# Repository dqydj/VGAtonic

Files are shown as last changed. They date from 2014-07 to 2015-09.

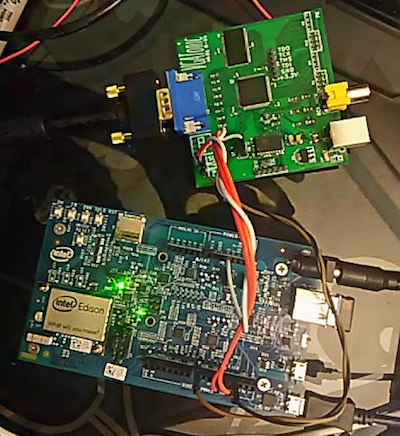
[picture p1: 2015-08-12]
Serial_Framebuffer_Demo/edison.png

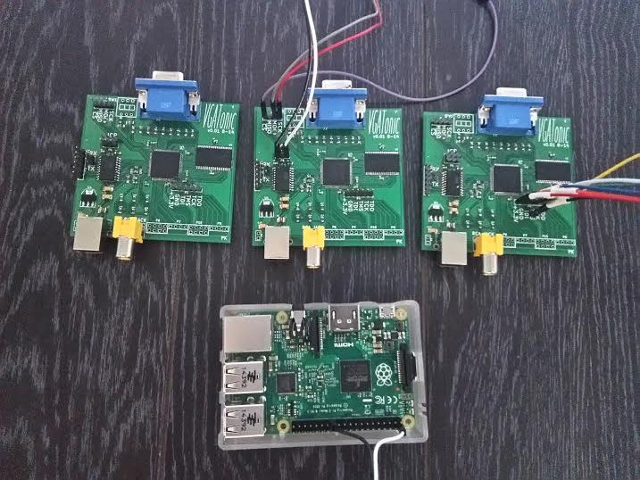
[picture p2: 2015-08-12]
Serial_Framebuffer_Demo/ground.jpg

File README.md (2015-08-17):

VGAtonic
========

4 MBit Video Card supporting up to 640x480 resolution and 8 bit color depth over SPI.  Outputs to any standard VGA Monitor.

**What it is:**

VGAtonic is a video card for adding graphics output to computers, microcontrollers, and devices with SPI output.  It can generally support 5v, 3.3v and 2.5v SPI without level conversion, and can accept SPI of up to 60 MHz (or higher), giving 24.4 FPS as a worst case top speed for it's highest resolution and color depth.  It is also an entry to the [2015](https://hackaday.io/project/6309-vga-graphics-card-vgatonic) and [2014](https://hackaday.io/project/1943-vgatonic) Hackaday Prize competitions.

It additionally has hardware supported accelerations for various things, meaning that slower SPI links can still have useful display output:

 - 640x480 resolution  
 - 320x240 resolution
 - 160x120 resolution
 - 80x60 resolution
 - 8 bit color (256 colors)
 - 4 bit color (16 colors)
 - 2 bit color (4 colors)
 - 1 bit color (black & white)

Last, it also *accelerates screen positioning*, so the entire framebuffer need not be updated for a single refresh (allowing, for example, a menubar at the bottom of the screen to be updated at the full 60 Hz possible in the 640x480 resolution mode).

Importantly, all of these accelerations stack, so if you have a 4 MHz link, you can choose to target, say, 160x120x4 bits for 52 FPS worst case.

**How it's made:**

See the entire parts list in [this Hackaday Prize post](https://hackaday.io/project/6309-spi-and-ttl-serial-vga-graphics-card-vgatonic/log/21984-updated-bill-of-materials).  As part of the project, to keep it *interesting* (and keep costs down) I used modestly spec'd parts - a 144 Macrocell Xilinx XC95144XL CPLD instead of a large FPGA, and an 8 bit 128-Bytes of RAM Atmel ATTiny 2313a Microcontroller instead of one of the larger Atmel parts or something 32-bit (it's not even the largest part in its footprint).  Additionally, the pixel clock is provided by Linear Technology's LTC6903, allowing it to be changed on the fly (and, undoubtedly, tuned for specific monitors) by the microcontroller.  

You can find the schematics in the Rev A directory..

As for the software:

 - KiCad for the layout and Schematic
 - VHDL on Xilinx's ISE Webpack for the CPLD
 - C/C++ for any Microcontroller and Computer glue
 - C for the kernel code for the VGATonic Linux framebuffer drivers
 - Python where necessary

**How it's licensed:**

MIT (Hardware, Firmware, Python Examples, Arduino Code)  

GPL (Linux Framebuffer Drivers, Linux Userspace Code)  

LGPL (Changes to Arduino-Tiny Core)

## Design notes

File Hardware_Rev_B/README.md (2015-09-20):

**NOTE:  This is the current version that should be built.  It has the NTSC pins and almost the same number of GPIOs broken out as Rev A on the optional unpopulated header on the back.**

**For VGA, there is no contest - build Rev B.  You will get more serial speeds, better ground isolation, shielding on the SPI signals, and... LEDs!**

By default, you should try the REGULAR firmware, not the WIDESCREEN firmware.  640x480 at 60Hz is industry standard, so that's the fallback (and it allows 320x240, 160x120 and 80x60 resolutions too for your slower parts or when you want to drive VGATonic over serial).  Once your board is working, the WIDESCREEN firmware is *much* nicer, but it only offers 848x480 and 424x240 resolutions.  It is only tested on rev B, but it likely works on rev A - just be careful.  Note, too, that the TERMINAL EMULATOR only works with the REGULAR firmware, it isn't yet updated for WIDESCREEN.

In this directory you'll find the design documentation for VGAtonic's second design, which we're naming v1.25 or "Rev B".  It is 39% smaller than the first version and contains 54 components (counting the headers and a single component each).

Returning are the Xilinx XC95144 CPLD, the ISSI IS61LV5128AL Memory, and the Linear LTC6903.

We've switched the Atmel 2313a up with the Atmel ATTiny 4313 (it's pin compatible), and clocked it with a 7.3728 MHz crystal which gives us magic frequencies to support lots of new serial speeds.  An external clock also saves us the optional calibration step in programming, which could be a bit of a hassle - now we'll have just two steps for the microcontroller, burning EEPROM then programming the rest.

Oh, we also added LEDs!  That, of course, is the best new feature.

License: MIT (see root directory)

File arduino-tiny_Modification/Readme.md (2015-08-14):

These two files are the minor edits I made to the Hardware Serial code in the arduino-tiny code, which you can find at https://code.google.com/p/arduino-tiny/

VGATonic needs these edits because it handles UART interrupts on its own.

As arduino-tiny is released under an LGPL license, I have included my modified files so you can reproduce my work exactly.

On a Mac, here's the path:

Arduino (Right Click) -> Show package contents

/Contents/Resources/Java/hardware/tiny/avr/cores/tiny/

(Replace the two Hardware Serial files)

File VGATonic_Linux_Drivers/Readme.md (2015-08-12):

**Raspberry Pi:**

Install all of the normal build tools and a recent gcc/g++. You may need an updated kernel - I'm using some 3.18 flavor (no device tree); you can match me like so:

> sudo rpi-update 07179c0ab486d8362af38c6fc99643ded953b99d  
> rpi-source  
> cd into Driver directory  
> sudo make clean  
> sudo make  

Once you've built, here is how you load VGATonic each time (you can automate this, of course!):

> sudo modprobe sysfillrect  
> sudo modprobe syscopyarea  
> sudo modprobe sysimgblt  
> sudo modprobe fb_sys_fops  
> sudo insmod vgatonic.ko  
> sudo insmod rpi_vgatonic_spi.ko  

(You should see activity. Or just do a 'cat /dev/urandom > /dev/fbX' to see writes!)

**Odroid C1:**

I'm on this kernel: Linux odroid 3.10.80-94 for all of these instructions.  Here is how I build on the Odroid:

> sudo -i  
> cd into VGATonic  
> make clean  
> make  

Once it is built, this is how you load it:

> sudo modprobe spicc  
> sudo modprobe spidev  
> sudo modprobe sysfillrect  
> sudo modprobe syscopyarea  
> sudo modprobe sysimgblt  
> sudo modprobe fb_sys_fops  
> sudo insmod vgatonic.ko  
> sudo insmod odroid_vgatonic_spi.ko  

**Beaglebone Black**

For the BeagleBone, you need to load a device tree overlay before anything else to turn on the SPI device.  Since SPI1 interferes with HDMI, I used SPI0.  Here is a tutorial: http://elinux.org/BeagleBone_Black_Enable_SPIDEV .  I do not use a device tree overlay for VGATonic in the driver (yet) for our control pin - so in theory, you should control other things writing to the pin you choose.  Still, this works for me in the 3.8.* kernel:

> cd VGATonic directory  
> make clean; make  

Beaglebone has a lot of stuff loaded for us already, so it's easier to load.

> echo BB-SPI0-01 > /sys/devices/bone_capemgr.*/slots #(assuming you followed the SPI tutorial above and used the default name)  
> sudo insmod vgatonic.ko  

**How Do I Know it Worked?**

There is a test pattern printed when you first load the driver for your platform.  You should see a pachwork of some sort - it is different than the green screen you get when giving VGATonic power for the first time.

The easiest way to know it worked, however, is to get it to react from your platform.  You'll have a new entry in /dev/fb*, so do this:

> cat /dev/urandom > /dev/fbX # X is the new framebuffer number  

You should see random pixels everywhere.  As for how to use your screen, check out the excellent resources Notro has compiled for fbtft.  I have generally tested these platforms by starting the x server then using a browser for a bit just to see how responsive it is.

License:

    VGATonic Linux Framebuffer Driver Code
    Copyright (C) 2015 PK

    This program is free software: you can redistribute it and/or modify
    it under the terms of the GNU General Public License as published by
    the Free Software Foundation, version 2 of the License.

    This program is distributed in the hope that it will be useful,
    but WITHOUT ANY WARRANTY; without even the implied warranty of
    MERCHANTABILITY or FITNESS FOR A PARTICULAR PURPOSE.  See the
    GNU General Public License for more details.

    You should have received a copy of the GNU General Public License
    along with this program.  If not, see <http://www.gnu.org/licenses/>.

> Written with [StackEdit](https://stackedit.io/).

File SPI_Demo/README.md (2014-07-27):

Please see the code for the full details of the implementation, but in summary:

* SPI Slave code with clock domain crossing
* Requires 2 clocks - one SPI clock from the sender, and a 'user mode' clock to run the logic
* Estimated speed is estimated by (3*tUSER + 2*tSU)/7.5 ns, invert for frequency 
        (and please check my math - no warranties implied)
* 2 Flip-Flop synchronization stage for clock domain crossing
* Single byte FIFO for passing SPI byte to user logic

License is MIT

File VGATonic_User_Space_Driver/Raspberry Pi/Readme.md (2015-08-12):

To use:

Edit the code, since we're assuming a 58 MHz SPI device (which isn't common!)

(If you need to build)

gcc raspi_user_spi_test.c -o spitest

(To run: You need a "spidev0.0" device!)

sudo ./spitest

Control-c to exit - but really, insert your code in the loop if you just want to write to the framebuffer!

License:

    VGATonic Linux User Space Code
    Copyright (C) 2015 PK

    This program is free software: you can redistribute it and/or modify
    it under the terms of the GNU General Public License as published by
    the Free Software Foundation, version 2 of the License.

    This program is distributed in the hope that it will be useful,
    but WITHOUT ANY WARRANTY; without even the implied warranty of
    MERCHANTABILITY or FITNESS FOR A PARTICULAR PURPOSE.  See the
    GNU General Public License for more details.

    You should have received a copy of the GNU General Public License
    along with this program.  If not, see <http://www.gnu.org/licenses/>.

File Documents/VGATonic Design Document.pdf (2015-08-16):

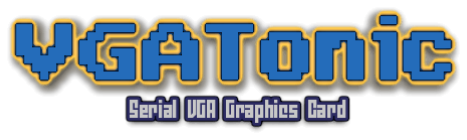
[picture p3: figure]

## VGATonic Serial Graphics Card Hardware System Design Document

## Version 1.0

PK

### 1. Introduction

VGATonic is an open source serial graphics card designed to enable graphical output for microcontrollers, single board computers, and other devices with SPI or Asynchronous TTL Serial output.

VGATonic provides up to 640x480 resolution in 8 bit color using standard VGA timings. The framebuffer memory can be accessed over both SPI and TTL UART.

VGATonic allows hardware accelerated resolutions of 320x240, 160x120, and 80x60. Additionally, it enables accelerated color bit depths of 4, 2, and 1 – and any combination of color depth and resolution. VGATonic also enables hardware accelerated positioning allowing partial frame updates.

In UART mode, VGATonic also exposes a VT52 compatible terminal emulator with 40x15 columns of text along with a built-in font.

### 1.1 Purpose

VGATonic was created as a graphics card with easy to use VGA output when provided input in serial format. It enables easily usable VGA output for low to medium serial speeds by allowing a designer to pick a combination of accelerated bit depths and resolutions acceptable for his or her design.

For applications where only text output is needed or framebuffer modes which fit the available serial speed are too slow, there is a VT52 compatible terminal emulator with a built-in font onboard.

### 1.2 Scope

This version of VGATonic is intended to provide graphical output over VGA in standard 640x480 at 60Hz timings. It requires a driver which can output SPI and/or asynchronous TTL serial, and requires a monitor, television, adapter, capture card, or other device providing VGA input as a consumer of its VGA output.

### 1.3 Overview

This document provides a brief description of some of the specific functions, design decisions, and technical specifications of VGATonic. It is hoped that the reader can create a design utilizing VGATonic's graphical output using this document, The User's Guide and supporting collateral such as schematics, example code, and drivers.

### 2. VGATonic Overview

### 2.1 Product Functions

### 2.1.1. Framebuffer Mode

VGATonic's main mode is a framebuffer mode. Utilizing an onboard 4 Mbit SRAM, VGATonic can accept pixel by pixel data in 8, 4, 2, or 1 bit color depths. VGATonic writes left to right and top to bottom, while the number of writes is determined by the resolution of the screen (and the bit depth). Other than 640x480, VGATonic also does power of two resolution reductions internally, accepting 320x240, 160x120, and 80x60.

VGATonic allows three forms of hardware acceleration in order to improve performance over serial connections. Please see the User's Guide for an in depth description of these modes and a description of the control characters that allow resolution and bit depth changes as well as write positioning.

- Chip Select
- Toggling chip select at any point during a serial transfer (chip select high then low) will reset the framebuffer write pointer to the upper left pixel at location 1 in row 1.
- Hardware Positioning
- Control characters can be used to change the location of the framebuffer write pointer. Positioning changes the row where a serial write will begin.
- Bit Depth and Resolution
- Changing bit depth and resolution from 640x480 in 8 bits primes VGATonic to accept fewer bytes in a given serial transaction.

### 2.1.2. Terminal Emulator Mode

VGATonic includes a terminal emulator onboard with one built in font. It is accessible over asynchronous TTL serial. It provides 40 columns by 15 lines of text and allows a subset (roughly 90%) of VT52 escape codes. Please see the User's Guide for a listing.

### 2.1.3. Administration Mode

Using special escape codes not available on the VT52, VGATonic exposes certain functionality useful for a serial graphics card. Connecting over asynchronous TTL serial, Administration Mode allows toggling UART speed between 9600 baud and 38400 baud. In the case that a device will not sync to VGATonic's VGA output, Administration Mode also allows calibration of the onboard LTC6903 programmable oscillator.

### 2.2 Product Constrains

- 5V Power (most commonly using USB-B input)
- SPI: 5v, 3.3v or 2.5v logic (1 byte transactions)
- (and/or)
- Serial: 3.3v 9600 or 38400 baud 8-N-1 logic

### 2.3 Product Assumptions

VGATonic assumes the availability of a VGA input device, such as a monitor, television, capture card, converter box, or other form of input. It also assumes compatibility with IBM's 1987 VGA standard timings for 640x480 resolution at 60 Hz. It also assumes the availability of a suitable 5 volt power source.

VGA's original 640x480 standard called for 16 colors (4 bit color), and VGATonic goes beyond that specification with 256 color (8 bit) mode available in all resolutions.

Although we assume all existing VGA monitors can handle (or ignore) the added color modes, if you have a classic monitor you will be connecting to VGAtonic please check the monitor's user manual first.

### 3. System Requirements and Specifications

### 3.1 Functionality

VGATonic outputs a constant 640x480 at 60 Hz signal and all processing for lower resolutions and color depths is done internally. VGATonic can multiplex writing and reading with a single buffering schema, and can accept SPI writes faster than the VGA pixel clock.

In UART mode, VGATonic starts up in 9600 baud 8-N-1, but can be toggled to 38400 baud.

### 3.2 Performance

### 3.2.1 Serial Maximum Speeds

- 59.7 MHz Maximum SPI Speed Recommended
- 62.5 MHz tested working on 100% of prototype boards, but technically violates CPLD setup times.
- 9600 or 38400 baud 8-N-1 Asynchronous Serial

### 3.2.2 Serial Voltages

- 5v, 3.3v, or 2.5v SPI
- 3.3v Asynchronous Serial (UART)

### 3.2.3 Resolutions, Bit Depths, and Bits Written

- 640x480 @ 256 Colors
- 2,457,600 bits per frame (307,200 bytes)
- 640x480 @ 16 Colors
- 1,228,800 bits per frame (153,600 bytes)
- 640x480 @ 4 Colors
- 614,400 bits per frame (76,800 bytes)
- 640x480 @ 2 Colors
- 307,200 bits per frame (38,400 bytes)
- 320x240 @ 256 Colors
- 614,400 bits per frame (76,800 bytes)
- 320x240 @ 16 Colors
- 307,200 bits per frame (38,400 bytes)
- 320x240 @ 4 Colors
- 153,600 bits per frame (19,200 bytes)
- 320x240 @ 2 Colors
- 76,800 bits per frame (9,600 bytes)
- 160x120 @ 256 Colors
- 153,600 bits per frame (19,200 bytes)
- 160x120 @ 16 Colors
- 76,800 bits per frame (9,600 bytes)

- 160x120 @ 4 Colors
- 38,400 bits per frame (4,800 bytes)
- 160x120 @ 2 Colors
- 19,200 bits per frame (2,400 bytes)
- 80x60 @ 256 Colors
- 38,400 bits per frame (4,800 bytes)
- 80x60 @ 16 Colors
- 19,200 bits per frame (2,400 bytes)
- 80x60 @ 4 Colors
- 9,600 bits per frame (1,200 bytes)
- 80x60 @ 2 Colors
- 4,800 bits per frame (600 bytes)

### 3.2.4 Theoretical Top Framerate for Full Screen Writes (SPI Only, 59.7 MHz)

- 640x480 @ 8 Bits Per Color: 24.29 Frames Per Second
- 640x480 @ 8 Bits Per Color: 48.58 Frames Per Second
- All other color and resolution combinations: 60 Frames Per Second

### 3.2.5 Power Usage

Typical*: 140 – 170 mA at 5V, 0.7 – 0.85 Watts

If there is a fault condition on the 5V power supply, the 750 mA PTC fuse aboard VGATonic should trip. Once you fix the fault, please wait for the fuse to cool down before providing VGATonic with power again. PTC fuses can take up to 24 hours (even more) to reset.

*VGATonic power usage varies based on mode (UART, SPI). As the VGA standard calls for VGATonic to source current, the average color of the pixels on screen and the rate VGATonic updates internal framebuffer memory also can cause a measurable change in the amount of power used.

### 3.3 Design Constraints

VGATonic was designed with a few requirements in mind:

- Low cost per board
- Ease of use
- Easy to use interfaces
- Very low to medium serial interface speed (No USB 2.0+, PCI, etc.)
- Highly constrained: challenge of CPLD and Tiny Microcontroller vs. FPGA and 32 bit microcontroller.
- Hackability: programmable oscillator and programmable logic and microcontroller
- Power consumption able to run off a USB port

3.4 Applicable Licenses

- MIT:
- All hardware - the PCBs and Kicad collateral.
- CPLD Firmware
- Microcontroller Firmware
- Arduino Framebuffer Driver
- UART Examples
- GPL version 2: (Kernel code and SPIDEV)
- All of the Linux Framebuffer Code
- The Linux User Space Driver code
- Third Party Licenses:
- LGPL:
- arduino-tiny core
- https://code.google.com/p/arduino-tiny/

### 3.5 Applicable Standards

- 8-N-1 3.3V TTL Serial at 9600 or 38400 baud
- SPI at 5v, 3.3v, or 2.5v
- (Commonly Mode 0 or 3, but there is no official SPI standard)
- 640x480 @ 60Hz Industry Standard (IBM) VGA timing
- VT52 Compatible Terminal Emulator Escape Codes

### 4. Parts Selection

(Footprints/PCB Part Labels are in Github)

1 × Xilinx XC95144XL 144 Macrocell CPLD
1 × Atmel Corporation ATTiny 2313a Microcontroller
1 × ISSI IS61LV5128AL-10 100 MHz 4MBit Static Ram
1 × Linear Technology LTC6903 Programmable Oscillator
1 × ON Semiconductor NCP1117ST33T3G 3.3V Low Dropout Voltage Regulator 12 × 0.1 uF Capacitor 0603 Capacitor
2 × 10 uF Capacitor 1206 Capacitor
1 × 47 uF Capacitor 1206 Capacitor
1 × 1 uF Capacitor
1 × Bourns MF USMF075-2 .75 Amp PTC Fuse
1 × USB-B Jack Power Supply, Multicomp USB-B-S-RA 1 × VGA Port TE Connectivity 1734344-1
6 × 10k Ohm Resistor 0805
1 × 4.7k Ohm Resistor 0805
4 × 510 Ohm Resistor 0805
5 × 1k Ohm Resistor 0805
4 × 2k Ohm Resistor 0805
1 × 4k Ohm Resistor 0805
1 × 1.5k Ohm Resistor 0805
1 × RCA Jack (Optional) Switchcraft PJRAN1X1U04X (For future optional firmware swap)

(Please see the User's Guide for a detailed build guide.)

### 5. System Block Diagram

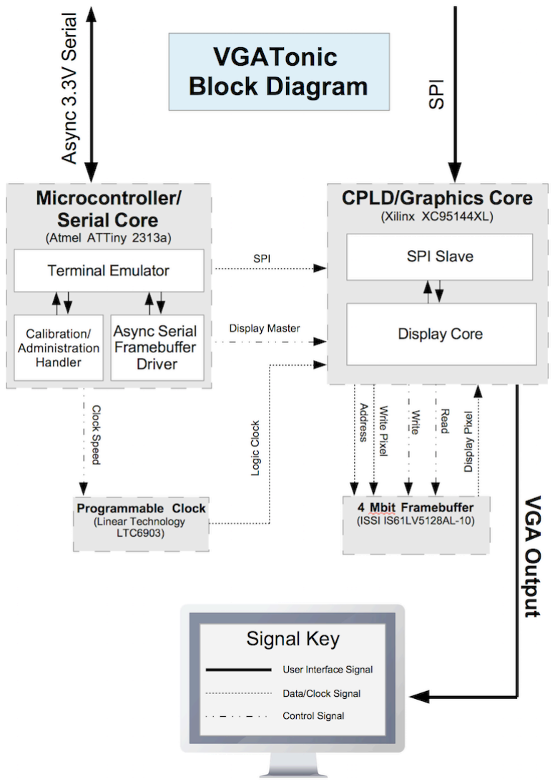
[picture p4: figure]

### 6. Future Work

There are two main places VGATonic could build towards:

VGATonic has sufficient GPIOs to develop RCA/component output, albeit not at the same time as VGA output. Eventually, it would be nice to have an alternative firmware for NTSC output. PAL output should also be doable.

VGTonic has sufficient framebuffer memory to target 800x600 at 8 bit color resolution. This mode isn't supported to the degree that 640x480 at 60 Hz is, but would be a valuable additional firmware for users to install for specific cases where more resolution was needed.

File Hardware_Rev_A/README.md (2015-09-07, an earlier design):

**NOTE: For most purposes, you should build REVISION B.  Please exit this directory and go to Rev B.  It is smaller, it doesn't require extra code to work around an error in the schematic, it supports more serial speeds, and it has better ground planes and shielding for SPI signals.  It also has LEDs!**

**The only reason you should build this version is for easy access to RCA and the GPIOs.  Revision B has all the same pins broken out on a .4mm pitch header, which is harder to access, but is superior in all other ways!8**

In this directory you'll find the design documentation for VGAtonic's first reference design, which we're naming v0.01 or "Rev A"

We've added three systems to the board to make it easier to develop the firmware.  An LTC6903 (http://www.linear.com/product/LTC6903 , up to 68 MHz) will handle the clocking duty for VGAtonic.  It is controlled by an ATTiny2313.  (I've routed a few additional lines between the CPLD and the ATTiny for user expansion.)

We've also added a Gadget Factory Papilio (http://papilio.cc/) compatible (other than the 2.5v pin) header at the bottom, with two slots.  16 CPLD GPIOs are routed there.  Another 3 are routed to the switch near the VGA connector.

All in all, about 3"x3", and $30 for 10 shipped from http://www.elecrow.com/ (DHL option when I purchased mine)

License: MIT (see root directory)

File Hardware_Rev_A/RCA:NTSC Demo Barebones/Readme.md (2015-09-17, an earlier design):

**This Firmware should ONLY be used with the Rev A version of the board, unless you populate the header on the back of rev B and build a DAC for the NTSC signals.  (That is left as an exercise for the rev B reader)**

*Also, this is a proof of concept - **you should use the VGA output**.  There are nonstandard frequencies everywhere, and it's luck of the draw how close the LTC6903 on your board will get to NTSC's colorburst frequency.  VGA is much more tolerant of small errors, while even being 15000 off NTSC's 3.57 MHz (that's just a .4% error!) burst will create a rainbow from a single color.*

To use this with a rev A Board:

 1. In the Microcontroller firmware, edit the LTC6903 programming lines until you have an acceptable color burst frequency.  Datasheet is here http://www.linear.com/product/LTC6903
 2. 	 bitbang_byte_out(0b11100001); bitbang_byte_out(0B10100110);
	 3. (In theory, DAC should be 100, but I needed to use 105.  I also got .07% error instead of .00%)
 3. Program the microcontroller
 4. Program the CPLD

The released firmwares should work if you set the speeds below 21.9 MHz SPI, and note that color depth is 4 bits while resolution is 320x240.  This might require recompilation.

As for the TTL Serial support?  It works, but only in framebuffer mode.  Send only 320x240@4bpp or you'll get weirdness on the screen.

After that?  Use it just like you would a regular VGA VGATonic - I've tested it on all three NTSC accepting screens here, and while the colors are all slightly different ('Never The Same Color' is a joke for a reason), they all attempt to produce a picture even with my non-standard colorburst frequency.

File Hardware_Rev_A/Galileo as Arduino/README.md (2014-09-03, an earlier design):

This code runs on an Intel Galileo modified as mentioned in this post:

http://hackaday.io/project/1943/log/8757-the-project-deadline-limbo

Once you increase the allowed sketch size your Galileo should have no problem running this code.

Pins needed:
13: SCK
11: MOSI
10: CS

Optional:
5v
GND

Steps:
1) Get the python script in this directory, edit the line which refers to picture name
2) Find a way to install the PIL, Python Imaging Library, http://www.pythonware.com/products/pil/
3) Format your picture as 640x480.  Optional: use Photoshop or similar to limit the color palette.
4) Copy guitars.h / doge3.h with the output of the script.
5) Upload, be wowed!

We'll do Linux next.

License: See main directory, still MIT.

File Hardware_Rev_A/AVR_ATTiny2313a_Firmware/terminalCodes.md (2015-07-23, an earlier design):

## VGATonic vt52 Compatible Escape Codes ##

Here is a list of vt52 compatible escape codes supported by VGATonic.  Due to the very small RAM (128 Bytes), there isn't enough room to implement any of the multi-line commands.  However, this covers the major commands for most applications.

Hit escape, then hit the following character to execute the commands:

    A - Move the cursor to beginning of line above.
    B - Move the cursor to beginning of line below.
    C - Move the cursor right by one.
    D - Move the cursor left by one.
    E - Clear the screen and place the cursor in the upper left corner.
    H - Move the cursor to the upper left corner.
    I - Move the cursor to beginning of line above.
    J - Erase all lines after our current line
    K - Clear the current line from the current cursor position.
    M - Delete the current line.
    Y - 'Goto' Coordinate mode - first will change line number, then cursor position (both ASCII - 32)
    b - Byte after 'b' sets new foreground color.
    c - Byte after 'c' sets new background color.
    d - Erase all lines above current line.
    e - Enable the cursor.
    f - Disable the cursor.
    l - Erase current line line and place the cursor at the beginning of the row.
    o - Erase the current line from the beginning to the current cursor.
    p - Invert background and foreground color.
    q - Invert background and foreground color.

Special VGATonic Only Escape Codes
----------------------------------

Hit escape, then hit the following character to execute the commands:

    % - Administrator Mode
    W - 'W'rite framebuffer mode (pass through pixels from UART, 255 at a time)
    Z - Send control character to VGATonic.  (Position or Resolution or Bit Depth change)
    m - Become 'm'aster of CPLD (Disable external SPI writes and put Microcontroller in control)
    r - 'r'elease CPLD (Allow external SPI writes)
    s - 's'elect CPLD (Warn CPLD a new frame write is coming)
    u - 'u'nselect CPLD (Inform CPLD current frame write is done)
  
  **Special VGATonic Only Administrator Escape Codes ( Esc-%-(code) )**
  
    < - 9600  Baud Serial Terminal (Default)
    > - 38400 Baud Serial Terminal
    + - Add one to LTC6903 PLL Scaler
    - - Subtract one from LTC6903 PLL Scaler
    & - VGATonic default PLL Scaler, 0B01011110
    | - Burn current PLL Scaler to EEPROM
  
  **When done with VGATonic escape modes, to get back to the serial terminal, here's what I do:**
  
    Escape - m     (master)
    Escape - s     (select CPLD)
    Escape - Z r ( 160x120 @ 8bpp screen)
    Escape - E     (Clear the screen)

**When calibrating a new VGATonic:**

    Escape - % - to decrease the pixel clock (That's a single minus)
    Escape - % + to increase the pixel clock
    Escape - % | to burn scaler to EEPROM (will retain between 
    powerups)
    
**If your monitor won't sync to the VGATonic clock:**

  Escape - % & to reset the LTC Calibration bit to factory
  Escape - % | to burn the factory bit to EEPROM

> Written with [StackEdit](https://stackedit.io/).

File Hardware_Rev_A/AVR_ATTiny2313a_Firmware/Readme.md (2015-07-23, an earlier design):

## Burning Firmware ##

This is a two step process.

The very first time you run, you should uncomment the line in AVR_ATTiny2313a_Firmware.ino which says:

    //#define EEPROM_UPDATE 1 // Uncomment when you want to write EEPROM, otherwise leave this alone.

The function updateEEPROM() in utilities.ino controls what happens during the EEPROM write.  You should change the:

    eeprom_update_byte (( uint8_t *) OSCALSPEED, 'K' );

line (or at least the 'K') to something.  I am making one board at a time, so I just send ‘u’ over serial at 9600 baud until I have a value which is 1/9600 seconds long.  See Jason Pepas’s example 
here: https://github.com/pepaslabs/CalibrateATtiny85OSCCAL 

The *second* run, comment that line out - you’re ready to program again.  Connect at 9600 baud and do this:

    Escape - m (Master mode)
    Escape - s (Select CPLD)
    Escape - Z - r (Set to 8 bit color depth at 160x120 resolution, since we don't know what we were in.)

Now send it a bunch of random characters - congratulations, you are talking to a serial terminal emulator… in only 128 Bytes of RAM!!!

It is based on vt52 escape codes, but… 128 bytes of RAM, so we can’t do multi-line functions, wraps, and inserts.  We handle most of the codes, however.  See terminalCodes.md for all of the codes.

> Written with [StackEdit](https://stackedit.io/).

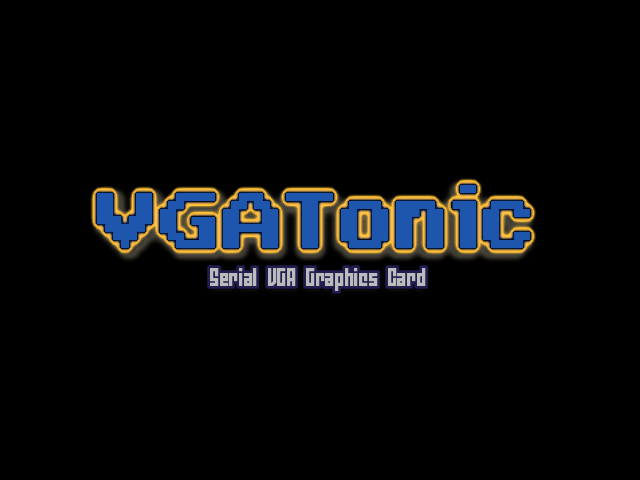
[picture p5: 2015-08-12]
Serial_Framebuffer_Demo/VGATonic.png

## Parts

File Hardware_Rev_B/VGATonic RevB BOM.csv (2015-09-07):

Reference | Value | Footprint | Cost / Board | Supplier | Quantity Required | Notes
IC1 | ATTINY4313 | Housings_SOIC:SOIC-20_7.5x12.8mm_Pitch1.27mm | 1.59 | Newark | 1
C1 | 0.1uF | Capacitors_SMD:C_0603 | 0.00359 | Digikey | 4000 | X7R
C2 | 0.1uF | Capacitors_SMD:C_0603 | 0.00359 | Digikey | 4000 | X7R
C3 | 0.1uF | Capacitors_SMD:C_0603 | 0.00359 | Digikey | 4000 | X7R
C4 | 0.1uF | Capacitors_SMD:C_0603 | 0.00359 | Digikey | 4000 | X7R
C5 | 0.1uF | Capacitors_SMD:C_0603 | 0.00359 | Digikey | 4000 | X7R
C6 | 0.1uF | Capacitors_SMD:C_0603 | 0.00359 | Digikey | 4000 | X7R
C7 | 0.1uF | Capacitors_SMD:C_0603 | 0.00359 | Digikey | 4000 | X7R
C8 | 0.1uF | Capacitors_SMD:C_0603 | 0.00359 | Digikey | 4000 | X7R
C9 | 0.1uF | Capacitors_SMD:C_0603 | 0.00359 | Digikey | 4000 | X7R
C10 | 0.1uF | Capacitors_SMD:C_0603 | 0.00359 | Digikey | 4000 | X7R
C11 | 0.1uF | Capacitors_SMD:C_0603 | 0.00359 | Digikey | 4000 | X7R
C12 | 1uF | Capacitors_SMD:C_0603 | 0.1 | Digikey | 1 | X7R
U3 | IS61LV5128AL | Footprints:tsop2-44 | 4.85 | Jameco | 1
U1 | LTC6903 | Housings_SSOP:MSOP-8_3x3mm_Pitch0.65mm | 3.92 | Digikey | 1
U2 | XC95144PQ100-100TQFP | Housings_QFP:TQFP-100_14x14mm_Pitch0.5mm | 7.25 | Digikey | 1
R2 | 4.7k | Resistors_SMD:R_0805 | 0.018 | Digikey | 10 | 5.00%
R1 | 10k | Resistors_SMD:R_0805 | 0.018 | Digikey | 10 | 5.00%
R3 | 10k | Resistors_SMD:R_0805 | 0.018 | Digikey | 10 | 5.00%
R4 | 10k | Resistors_SMD:R_0805 | 0.018 | Digikey | 10 | 5.00%
FID1 | CONN_01X01 | Fiducials:Fiducial_1mm_Dia_2.54mm_Outer_CopperTop | 0 |  |  | 5.00%
FID2 | CONN_01X01 | Fiducials:Fiducial_1mm_Dia_2.54mm_Outer_CopperTop | 0 |  |  | 5.00%
R11 | 510 | Resistors_SMD:R_0805 | 0.021 | Digikey | 10 | 1.00%
R12 | 1k | Resistors_SMD:R_0805 | 0.021 | Digikey | 10 | 1.00%
R13 | 2k | Resistors_SMD:R_0805 | 0.021 | Digikey | 10 | 1.00%
R8 | 510 | Resistors_SMD:R_0805 | 0.021 | Digikey | 10 | 1.00%
R9 | 1k | Resistors_SMD:R_0805 | 0.021 | Digikey | 10 | 1.00%
R10 | 2k | Resistors_SMD:R_0805 | 0.021 | Digikey | 10 | 1.00%
R5 | 510 | Resistors_SMD:R_0805 | 0.021 | Digikey | 10 | 1.00%
R6 | 1k | Resistors_SMD:R_0805 | 0.021 | Digikey | 10 | 1.00%
R7 | 2k | Resistors_SMD:R_0805 | 0.021 | Digikey | 10 | 1.00%
F1 | 0.75A HOLD 6V PTC | Resistors_SMD:R_1210 | 0.2544 | Newark | 10
U4 | NCP1117ST33T3G | Footprints:SOT223_PWR | 0.49 | Digikey | 1 | LDO Not Needed
C14 | 10uF | SMD_Packages:SMD-1206_Pol | 0.4848 | Newark | 5 | Tantalum, 6.3V
C15 | 10uF | SMD_Packages:SMD-1206_Pol | 0.4848 | Newark | 5 | Tantalum, 6.3V
C13 | 47uF | SMD_Packages:SMD-1206_Pol | 0.0672 | Newark | 1 | Tantalum, 6.3V
P6 | CONN_02X03 | Pin_Headers:Pin_Header_Straight_2x03 | 0.06
J2 | VGA-HD-15 | Footprints:HD15_B-HD15F | 1.18 | Newark | 1 | Newark 54M6031
C16 | 22pF | Capacitors_SMD:C_0603 | 0.024 | Digikey | 10 | X7R
C17 | 22pF | Capacitors_SMD:C_0603 | 0.024 | Digikey | 10 | X7R
Y1 | 7.3728 MHz | crystal:HC49_sm | 0.325 | eBay | 20 | MFG Not Important
P1 | CONN_01X03 | Pin_Headers:Pin_Header_Straight_1x03 | 0.03
P2 | CONN_01X05 | Pin_Headers:Pin_Header_Straight_1x05 | 0.05
P3 | CONN_01X02 | Pin_Headers:Pin_Header_Straight_1x02 | 0.02
P4 | CONN_02X03 | Pin_Headers:Pin_Header_Straight_2x03 | 0.06
P7 | CONN_01X30 | Footprints:DF40C-30DS-0.4V |  |  |  | Optional
D1 | Green LED | LEDs:LED-0603 | 0.0495 | Jameco |  | You Pick Color
R14 | 330 Ohm | Resistors_SMD:R_0805 | 0.212 | Digikey |  | 5.00%
R15 | 150 Ohm | Resistors_SMD:R_0805 | 0.212 | Digikey |  | 5.00%
R16 | 150 Ohm | Resistors_SMD:R_0805 | 0.194 | Digikey |  | 5.00%
D2 | Yellow LED | LEDs:LED-0603 | 0.0495 | Jameco |  | You Pick Color
D3 | Orange LED | LEDs:LED-0603 | 0.0495 | Jameco |  | You Pick Color
P5 | USB_B | Connect:USB_B | 0.5528 | Newark |  | Newark 14N8154
 |  |  | 22.88399

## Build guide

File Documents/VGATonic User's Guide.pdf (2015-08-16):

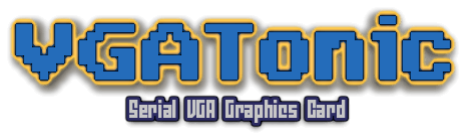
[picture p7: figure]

# User Guide and Reference Manual

# Getting Started

Providing Power
VGATonic needs to be provided with 5V in order to work.

Connect VGATonic's USB Type B port to an open USB port on the device which will be using the VGATonic video card. (If there are no USB ports available or you would prefer to power VGATonic in another way, please see the power labels on the PCB picture in the Appendix.)

Note that if you don't power VGATonic from the board you will be using to drive it, you should also connect a jumper between ground on the driver and ground on VGATonic to have a good reference. See the Appendix for grounding points onboard VGATonic.
Connecting VGA
Once power is provided to the board, connect a VGA cable between VGATonic's VGA port and a VGA port on your monitor, TV, converter, or other device.
Be careful you do not connect VGATonic to a device which provides VGA output – you can destroy VGATonic or the other device! Double check you are only connecting VGATonic to an output device or a converter which accepts VGA input.
If all is connected and your device didn't already autodetect VGATonic, switch your device on and set the device's input to VGA. You may need to read the user manual for instructions on how to do that for your unique situation.
VGATonic starts up with an all green screen; if your device is connected to VGATonic and displays a green screen – congratulations, VGATonic is powered up and working! You are now ready to pick a mode and start using VGATonic as a framebuffer or terminal emulator!

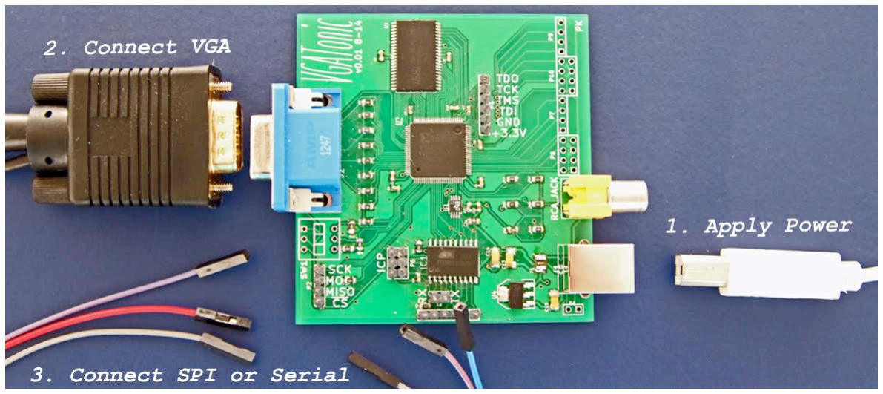
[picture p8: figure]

## VGATonic Usage Modes – Connecting SPI and Serial

VGATonic has two main forms of communication which are available – 5v/3.3v/2.5v SPI or 3.3v Asynchronous Serial (also known as “TTL RS-232” or “TTL Serial”). Using those protocols, three display modes and one administration mode are available:
SPI:
- Framebuffer
TTL Serial:
- Framebuffer
- VT52 Compatible (Subset) Terminal Emulator
- Administration Mode

You may use Serial and SPI at the same time, although only one can be the master at once.

## SPI Modes

SPI Framebuffer
The only available SPI mode is the SPI framebuffer. The easiest way to get started with SPI is to use the drivers we provide on Github and one of our supported boards, although we have provided enough examples for you to port to the platform of your choice. As of this printing, we have provided driver examples for the Raspberry Pi 2 Model B, The Odroid C1, the BeagleBone Black, and the Intel Edison with Arduino Breakout Board. We have also provided user mode drivers and Arduino driver code. The SPI header onboard VGATonic contains “SCK”, “MOSI”, “MISO” and “CS” (Chip Select) pins -but “MISO” can go unconnected. The pins in the table are board dependent and go by the board's naming conventions. You can, of course, change these in the drivers, but these are what we used and must be used if you do not change code:

For a description of the SPI protocol in order to write your own driver, please see the Hacker's Guide, or take a look at some of the code in our repository.

| Chip Select | MOSI | SCK | CS Label | MOSI Label | SCK Label
Raspberry Pi 2 Model B | 22 | 19 | 23 | BCM 25 | BCM 10 (MOSI) | BCM 11 (SCLK)
Odroid C1 | 22 | 19 | 23 | #103 | #107 | #105
BeagleBone Black | 15 | 18 | 22 | GPIO_48 | SPIO_D1 | SPIO_SCLK
Intel Edison | 8 | 11 | 13 | 49 | 43/SPI_2_TXD | 40/SPI_2_CLK
Arduino Uno | 9 | 11 | 13 | 9 | 11 | 13

## Asynchronous Serial Modes

VT52 Compatible Terminal Emulator

VGATonic includes a VT52-like terminal emulator, which provides a subset of VT52 escape codes as well as VGATonic specific (and unique – do not try on a working VT52) escape codes and administrator escape codes. It also includes a single font in memory.
When VGATonic starts up, it quickly initializes the oscillator and prints a green screen, and puts the SPI bus in charge of the VGA Output. In order to use the terminal emulator, you must connect over serial and put the terminal emulator in charge. Connect over TTL Serial at 9600 baud 8-N-1 (please see your serial device's manual for information on how to connect; it is beyond the scope of this document. On a Macbook, I use a USB to Serial Adapter and the 'screen' program in a terminal to connect.) The TX and RX pins onboard VGATonic should be used to connect to serial – ensure you properly connect your serial device.

Escape m # (Master mode)
Escape s # (Select CPLD)
Escape Z r # (Set to 8 bit color depth at 160x120 resolution, since we don't know what we were in.)

To ensure the serial connection now has control of the display driver, you can now send ASCII characters to VGATonic and see if they are printed on your screen. 'Escape E' (capital 'E') clears the screen and moves the cursor to the upper left.
If it works – congratulations! The terminal emulator is simply the easiest way to add VGA output to a project, as the serial protocol is widely supported at 9600 baud. Any microcontroller or TTL serial output that supports 8-N-1 serial at 3.3 volts can communicate with VGATonic and display characters and colors on the screen. It is particularly useful as a debugging output window for projects with serial available.
A complete copy of all codes supported can be found in the Appendix. Information on how to use high-speed 38400 baud mode is in the Administration section below.
To give control of the display driver back to the SPI connection, either power cycle VGATonic or use this command sequence over serial:

Escape Z r 0 (Set to 8 bit color depth at 640x480 resolution, since we don't know what we were in.) Escape u # (Unselect CPLD)
Escape r # (Release master mode)

Asynchronous Serial Framebuffer

While using the terminal emulator, VGATonic has special escape codes which allow you to directly write pixels to the screen. While 640x480x8bpp will be painfully slow even at 38400 baud, with modest resolutions like 80x60x1bpp you can get a usable framebuffer even over serial!
The escape characters needed are printed in the Appendix. Please see the Hacker's Guide and the python example provided on Github for a description of how to write directly to the framebuffer over serial.

Administration Mode

The terminal emulator also has an administration mode which allow custom settings for your VGATonic. A listing of all codes can be found in the Appendix; provisions are included for toggling the serial speed between 9600 and 38400 baud, as well as adjusting the PLL on the programmable clock in order to better sync to your monitor. (Please see the Troubleshooting Guide for more on calibration.)

# Troubleshooting Guide

Sometimes things don't work as expected! Here is a list of common problems, and
things to check in order to attempt to fix them.
VGATonic Won't Power On!
If USB is connected properly, connect another device to the USB port you are using in order to check if power is coming from the USB port. Alternatively, VGATonic can be powered through other pins on board – see the Appendix for details. When not using USB: always connect ground first, only use +5V pins to provide power, and only use one power source at a time!
VGATonic Won't Display Over VGA!
First check VGATonic is powered, then try a different VGA cable. Also, check your monitor settings to ensure your monitor is set to VGA input on the port VGATonic is connected to.
Most if not all monitors which adhere to the VGA standard or VESA modes will sync to VGATonic, but we are unable to test every individual device to ensure perfect compatibility. It's possible the PLL is set incorrectly too; see the section on resetting the PLL to factory below if you think this is the case (usually the monitor will have a notice or indication it cannot sync). Analog monitors will likely provide the best user experience, if available.
My Monitor Won't Sync to the VGATonic Signal!
From factory, VGATonic is .0119% out of spec from the VGA clock; a standard monitor will only have issues with between 0 and 49 displayed pixels, total, in our top mode. If you think you have changed the clock setting inappropriately in Administrator Mode, you can reset the PLL to factory easily. Power cycle, connect over serial at 9600 baud 8-N-1 and issue the following commands:

Escape % & # to reset the LTC Calibration bit to factory
Escape % | # to burn the factory bit to EEPROM
My Serial Connection Isn't Working!
VGATonic starts in 9600 baud 8-N-1 mode, but can be changed to 38400 mode. Try using the speed you aren't currently connecting at; if that doesn't work, power cycle VGATonic and connect at 9600 baud 8-N-1. Be sure you are using 3.3V serial – RS-232 voltages can destroy VGATonic!
VGATonic Won't Respond to SPI or Serial Writes!
First, ensure the bus you want is the master of the Display Core. After a power cycle, SPI will be in charge – see the section on the VT52 Compatible Framebuffer for information on how to change it. VGATonic is Working but My Colors Are Suddenly Inverted/Don't Match What is Expected!
If VGATonic was previously working, the most common cause of this is poor signal integrity – the chip select line is particularly sensitive to interference. The easiest way to clean it up is to twist 5v power or ground supplies around sensitive signals. You may need to power cycle.
SPI Won't Respond/SPI is Causing Garbled Output!
There are many things to check here, so this is not a complete list:
- How fast is SPI Running? VGATonic is in spec up to 59.7 MHz SPI, although we have tested at up to 62.5 MHz successfully.
- How is Your Signal Integrity? At faster speeds, long wires become antennas. Ensure your wires are as short as possible, with strong and firm connections to both your device and VGATonic. It usually helps to use twisted pairs; wrap power or ground signals around your SPI signals to cancel out some coupling issues. Here is some example routing with a BeagleBone Black. Note USB is not used for power in the image... if it is, only add ground connections:

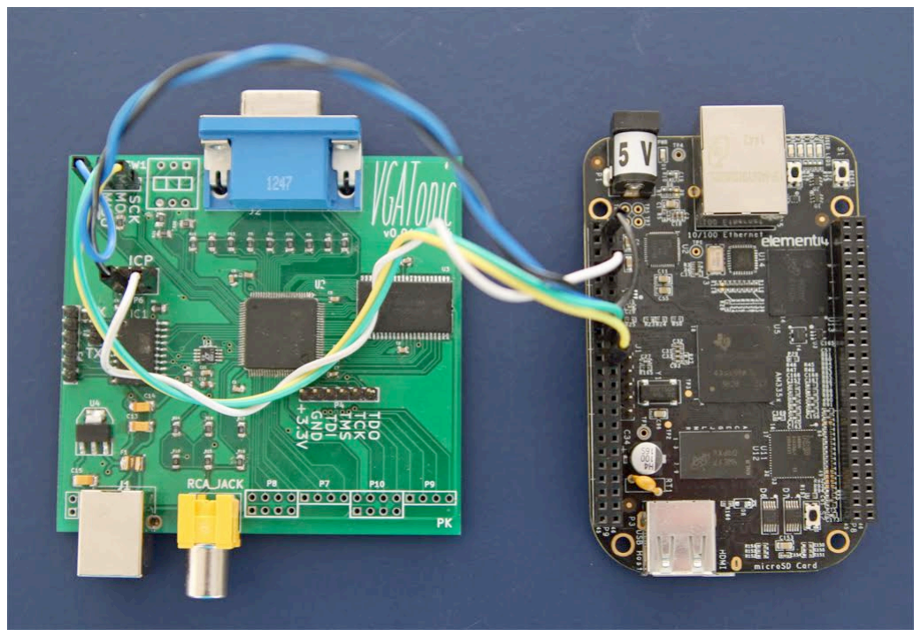
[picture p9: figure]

- Which SPI Mode is Running? VGATonic works 'best' in SPI mode 3 or 0 on most hardware, but because SPI is a loose standard, please try 1 and 2 if that isn't working. (You will need to make this change in software, which is beyond the scope of this booklet.)
- Is SPI Correctly Output? Due to hardware differences, we can't test every SPI implementation – but please ensure you are getting SPI as expected from your hardware.
- What's Your Ground Reference? If VGATonic is physically separated from its driver, run a jumper between ground (as short and/or thick as possible) on the two modules to have a common reference voltage.
- Is Chip Select Working Properly? Chip select is fraught with issues on many boards; it is easiest to use a software controlled chip select because VGATonic does up to 307,200 byte writes. For that reason, use software chip select for control. Additionally, double check CS signal integrity. My Picture Isn't Perfectly Stable! There is Pixel Drift and/or Jagged Lines!
VGATonic prioritized hackability over perfect stability - eschewing a crystal oscillator for a programmable oscillator. That opens up more future features, but you may see minor dot crawl or other analog artifacts on your monitor. We also drove to keep costs low, and VGATonic managed to arbitrate reads and writes in single buffering onboard instead of more expensive schemes like double buffering. Anyway, there are things you can try in order to clean up before you beg for HDMI:
- Lower bit depths toggle outputs multiple time based on a single write, while more bits per color will toggle more slowly. If you can, use higher bit depths.
- Noise on the MOSI line can make the screen look 'torn'. Noise on the chip select line, on the other hand, might show up as rapidly changing modes or partial writes.
- Most new monitors allow you to fine tune for phase and clock frequency – check your monitor settings and try to adjust both sliders. Let VGATonic warm up before calibrating your monitor.
- VGATonic allows you to adjust the value of the onboard LTC6903 programmable oscillator easily over asynchronous serial. You can try adjusting the clock up and down and see how your monitor or TV reacts. When you find an acceptable setting, you can burn it to EEPROM. See the Hacker's Guide for more information.

# Hacker's Guide

VGATonic was initially developed for Hackaday's 2014 and 2015 Prize Competitions – so a key philosophy in the design is hackability and openness. This led me to add fun features like a programmable oscillator and easy-to-program silicon like a microcontroller and a CPLD to the mix, along with (unpopulated) prototyping pins and space to add switches.
When all was said and done, VGATonic ended up with four main components – the CPLD, the Microcontroller, the Programmable Clock, and a 4 Mbit SRAM to hold our display data. The firmware to the CPLD and the Microcontroller are open source, and I've included examples of protocols and framebuffer drivers in Linux for the SPI and the Asynchronous Serial framebuffers. Of course, the VT52-like Terminal Emulator is also available – surely there have been more than a few games written in the past which used only ASCII! Regardless, this section houses details which a general user doesn't need to know to enjoy VGATonic – but power users and folks who love to tweak and push the limits will find this information... enlightening!

# SPI on VGATonic

SPI is the highest speed interface available to VGATonic, and you will get the best framerates and highest quality output targeting SPI. It has no minimum speed, and the highest recommended speed is 59.7 MHz. Faster speeds should work, but they violate the setup time of the CPLD's buffers – so you might have issues past 60 MHz. As always, keep connections short and clean while minimizing interference, and if you see signal integrity issues try twisting wires and shielding your sensitive signals (especially chip select) with 5v power or ground jumpers.
SPI Control Characters

For the SPI Framebuffer, there are two main ways to manipulate VGATonic.
1. The 'Chip Select' Signal
- Chip Select will reset the pixel counter to 0,0 (the upper left) to allow a new screen write.
- If a 'single' pixel is written, VGATonic will treat that pixel as a control character.
2. Control Characters
- One type of control character allows you to change VGATonic's mode.
- Another type controls cursor positioning, allowing hardware acceleration. Control characters work like this:

SPI Chip Select Starts High, then
SPI Chip Select Low
Send exactly one byte of data (this is the 'control' character)
SPI Chip Select High
You can send as many control characters as you want, but only the last sent character to VGATonic will determine behavior. VGATonic does not send any sort of acknowledgement, other than, perhaps, changing the addressing on the screen – you should see mode changes immediately.

Control Character Type I: Changing Bit Depth and Resolution
Writing control characters that start with '0' in the MSB will allow you to change resolutions and bit depths of VGATonic.
Our resolution modes differ from software resolutions or 'virtual' resolutions. To the monitor or display itself, VGATonic will always present timing of 640x480 @ 60 Hz – so you don't have to worry about compatibility issues with lower resolutions as long as 640x480 works! VGATonic does this internally – it controls how long to 'wait' on a pixel, so the driver tells it how many bytes to expect by setting the mode. Every drop in resolution is a halving of both width and height, so FPS potential will be 4x as much for each reduction (up to our maximum of 60 frames per second due to VGA timing). Our bit depth modes are similar. While on many video cards you would have to write, say, 16 or 24 1s to signal 'white' in Black and White mode, VGATonic will internally convert between color palettes... so a single byte sent might mean 1 (8 bit), 2 (4 bit), 4 (2 bit), or 8 (1 bit B&W) actual pixels written! In essence, every 'drop' in color depth doubles the frame speed potential. For example: a 25 MHz SPI part can do about 10 frames per second in 640x480x8bpp, but 20 frames per second at 640x480x4bpp. Control bits for changing bit depth and resolution work like this (where location '7' is the MSB and '0' is the LSB, or last bit sent in the byte). Bits 6, 5, and 4 are ignored – write whatever you like.
Bits 3 and 2: Bits Per Pixel/Color Depth
- 00 – 8 Bits Color Per Pixel (256 Colors)
- 01 – 4 Bits Color Per Pixel (16 Colors)
- 10 – 2 Bits Color Per Pixel (2 Grays, Black, White)
- 11 – 1 Bit Color Per Pixel (Black and White)
Bits 1 and 0:
- 00 – 640x480
- 01 – 320x240
- 10 – 160x120
- 11 – 80x60
You can, of course, change both at the same time:
b00000110 : tells VGATonic to set 4 bits per pixel color at 160x120 resolution.
Note that control pixels are wonky on single board computers or things without cycle accurate timing – if they are blocked from an SPI write (for example, during a video or game where the CPU is too busy to service another SPI write) – you may need to send more than one mode change to get it through. Setting the mode multiple times (even if all are successful) won't hurt VGATonic. This is part dependent and beyond the scope of this document, but if you don't see responses from a single board computer this is the first place to check.

Control Character Type II: Hardware Acceleration
VGATonic allows for hardware acceleration – it can skip to certain rows to begin writing new pixels. Writing a single pixel with a '1' in the MSB will cause the remaining bits to become the MSBs of the address bits of the next pixels written. Note that each resolution and bit depth reduces the number of addresses that are used:
- A control byte of '11110011' would use bits '1110011' in the address MSB (dropping the first '1'). There is an implied '00' added onto the end as the addresses themselves are 10 bits.
- For 640x480, a control character of 11100000 would set the next write at row “0b0110000000” or row 384.
- For 160x120, a control character of 11100000 would set the next write at row 0b01100000 or row 96. This is how it works:
- Start at “0b0110000000”, then >> 2 (320x240 shifts 1, 160x120 shifts 2, 80x60 shifts 3).

SPI Framebuffer
The SPI framebuffer is extremely straight forward, and was designed with the highest possible throughput in mind. The only overhead is the chip select, which pulls double duty to reset VGATonic's writing buffer to 0,0 (the upper left pixel). The protocol is as follows:

SPI Chip Starts High
SPI Chip Select Low
Send more than one SPI byte (up to 307,200 for 640x480x8bpp)
SPI Chip Select High – resets to 0,0
The number of pixels contained in each SPI byte is dependent on your color depth. The base mode is 8 bits per color, so every byte will represent a single pixel. All four accelerated depths look like this internally to VGATonic:
8 Bits: RRRGGGBB | (1 Pixel)
4 Bits: RGBI RGBI | (2 Pixels or RGB and Intensity, where '1' is 'bright')
2 Bits: HL HL HL HL | (4 Pixels of high/low)
1 Bit: I I I I I I I I | (8 Pixels of '1' = white and '0' = black)
Since the Chip Select controls the 'reset' for writes, you can stop writing at any time after at least 2 bytes are sent. This is useful if, for example, you are redrawing a cursor at the top of the screen. In conjunction with the hardware acceleration, it means VGATonic can quickly update any position in the screen, even if a full screen refresh would be very slow.
A combination of hardware acceleration and non-fullscreen writes can actually open up different 'accelerated' resolutions – consider using the acceleration to jump down a number of rows, then only writing the number of rows needed for your 'virtual' resolution, then pulling CS high again. If you are only doing partial screen refreshes, this means you can effectively update the screen faster than your SPI speed would otherwise support.

# Asynchronous 3.3v Serial on VGATonic

Onboard VGATonic is a 3.3v compatible serial interface to the microcontroller. It exposes 9600 baud and 38400 8-N-1 serial modes at TTL voltages, and allows you to control administration features of VGATonic – and it also manages to fit a VT52 Compatible Terminal Emulator and a framebuffer onboard!

VT52 Terminal Emulator
VGATonic's terminal emulator is technically always running, as soon as VGATonic is turned on and the startup routine has completed. However, the microcontroller will not be the master of the Display Core by default – this sequence will grab control (it will not hurt VGATonic if it already has control though, perhaps from a past terminal session):

Escape m # (Master mode)
Escape s # (Select CPLD)
Escape Z r # (Set to 8 bit color depth at 160x120 resolution, since we don't know what we were in.)
Escape E # (Optional, clears the screen)
After you have control of the terminal emulator, attempt to send ASCII characters to the screen to verify you are now the master of the Display Core. You now are using a terminal emulator with only 128 bytes of RAM! VGATonic supports 40 characters by 15 columns, and has one built in font.
VGATonic supports most VT52 escape codes... although a few are unimplemented because the microcontroller only has enough RAM to keep track of position, status, the UART ring buffer, and the current line. However, it does allow you to change lines – it will just enforce line clears for every line change. It also supports 256 colors for background and foreground colors – an improvement on the VT52 compatible 16 color modes.
As for typical ASCII, 'backspace' and/or 'delete' are supported, as well as the 'newline'/'carriage return'. Other ASCII characters are ignored, except, of course, 'escape' (ASCII 27).
For a full listing of VGATonic escape codes, see the Appendix.
Giving control back to the external SPI interface is really just the reverse of grabbing control. Here is an example sequence to put SPI back in charge of the Display Core:

Escape Z r 0 (Optional, sets to 8 bit color depth at 640x480 resolution, or whatever you want)
Escape u # (Unselect CPLD)
Escape r # (Release master mode)

Administrator Mode
VGATonic has an administrator mode, which allows you to fine tune the clock speed of the LTC6903 to improve compatibility with your display, and it also allows you to toggle between 9600 and 38400 baud 8-N-1 serial. It is important to note that VGATonic always starts in 9600 baud mode – for newer parts, it's suggested to change to 38400 baud immediately.
To enter administration mode, connect over serial, then use the escape sequence 'Escape %' (ASCII 27, 37) to open up options:

< - 9600 Baud Serial Terminal (Default)
> - 38400 Baud Serial Terminal
+ - Add one to LTC6903 PLL Scaler
- - Subtract one from LTC6903 PLL Scaler
& - VGATonic default PLL Scaler, 0B01011110
| - Burn current PLL Scaler to EEPROM
Administrator mode is most useful for changing serial speed, but it can also calibrate the onboard programmable oscillator, the LTC6903. By default, VGATonic programs the part at roughly 50.344 MHz. If you have changed calibration and your monitor will no longer attempt to sync, you can reset the oscillator like this:

Escape % & # to reset the LTC Calibration byte to factory
Escape % | # to burn the factory byte to EEPROM
We suggest trying to calibrate your monitor to VGATonic first, before attempting to calibrate VGATonic. However, if you would like to change VGATonic's oscillator clock speed, you can use these sequences to try new speeds:

Escape % + to increase the calibration by 1 (see LTC6903 datasheet for details)
Escape % - to increase the calibration by 1 (see LTC6903 datasheet for details)
Escape % | # to burn the new calibration to EEPROM
Graphics Control Mode
VGATonic exposes the control characters available to SPI to the terminal emulator as well. Hardware acceleration works, but utility is diminished from SPI since framebuffer mode requires a multiple of 150 byte sends – which is 1,200 black and white pixels (a far cry from the 2 pixel minimum write in SPI at 256 colors!). Bit depth and resolution changing is more useful.
You need to ensure that the microcontroller is in master mode. See the Control Character section in the Hacker's Guide for details. Here is an example sequence:

Escape m # (Optional, yet mandatory at start set master mode)
Escape Z # (Control byte incoming)
Send exactly one byte of data representing a control character
All Unique VGATonic Escape Codes:

% - Administrator Mode
W - 'W'rite framebuffer mode (pass through bytes from UART, 150 at a time)
Z - Send control character to VGATonic. (Position or Resolution or Bit Depth change)
m - Become 'm'aster of CPLD (Disable external SPI writes and put Microcontroller in control) r - 'r'elease CPLD (Allow external SPI writes)
s - 's'elect CPLD (Warn CPLD a new frame write is coming)
u - 'u'nselect CPLD (Inform CPLD current frame write is done)

Asynchronous Serial Framebuffer
We couldn't leave the microcontroller alone without one last essential feature – a Serial Framebuffer Mode!
Since VGATonic's top serial speed is a modest 38400 baud, most resolutions and bit depths are more of a 'slideshow' mode... so calling it a 'framebuffer' is charitable. However, if your video application can stand 80x60 resolution, you can get ~ 5.2 frames per second in Black and White or ~ 2.6 frames per second in 2 bit color at 38400 baud.
For most video applications, you are better off using SPI. Serial applications are best served by the VT52 emulator, but for specific applications such as digital signage the framebuffer mode is very nice to have.
If you would like to try the serial framebuffer, this is how the protocol works:
1. (Optional) Set mode/resolution as detailed in the Graphics Control Mode section above.
2. Send VGATonic an Escape character (ASCII 27)
1. VGATonic responds '>' (ASCII 62)
- If VGATonic doesn't respond with anything, you can send escape characters until you get 'DC1' (ASCII 17) or '>' (ASCII 62) - it likely was halted during a framebuffer write.
- If VGATonic responds with nonsense, you are likely in the wrong serial speed – either 9600 baud or 38400 baud. See the administrator mode section for how to change speeds, or use the other speed.
3. Send VGATonic a 'W' character (ASCII 87)
1. VGATonic responds with 'ACK' (ASCII 6)
4. Send VGATonic 150 Bytes
1. After last byte, VGATonic responds with 'DC1', Device Control 1 (ASCII 17)
5. Repeat as desired!

# Building and Programming VGATonic

Want to build VGATonic from scratch? That's the spirit! Grab our latest hardware on Github and fire up your iron.

Prerequisites: Steady hand, soldering iron, parts, Xilinx Programmer or XSVF Player, USBTiny ISP (or other Atmel programmer for ICSP), Xilinx ISE Webpack Software, Recent Vintage Arduino IDE with arduino-tiny installed and all hardware serial files commented out: https://code.google.com/p/arduino-tiny/

The CPLD

1. Solder on the CPLD, U2
2. Solder on the decoupling capacitors next to the CPLD (C1, C3, C5, C7, C8, C9, C10) and the 6 pin header needed to program the CPLD – these pins are marked “TCO”, “TCK”, “TMS”, “TDI”, “GND” and “+3.3V” and labeled P4.
3. Check for shorts between power and ground, ensure your chip is oriented correctly, etc.

The Power Supply

1. Solder on capacitors C15, C14, and C13
2. Add fuse F1
3. Add 3.3v Regulator U4
4. Finally, solder on USB B power jack J1
5. As always, check for shorts, double check all your work, check orientation, etc.

Programming, Part I

1. (Assuming everything is ready!) Apply power
- If there is a short, the PTC fuse should get very hot, but shut down the board quickly.
- Fix this condition before continuing! The PTC might take quite some time before resetting, anyway – you've got time.
2. Hook up your Xilinx programmer (or XSVF player, but that is beyond the scope of this document). ISE Webpack will program this part.
3. Initialize chain – if it comes back with the right part, the CPLD was soldered correctly!
4. If you're still going, burn the CPLD with the firmware! Congratulations, the hard part is done!
5. REMOVE POWER BEFORE CONTINUING

Framebuffer Memory
1. Solder on 4 Mbit SRAM, U3
2. Add decoupling capacitors C2 and C6

Programmable Oscillator
1. Add the programmable oscillator, U1
2. Add decoupling capacitors C11 and C12
3. Add SPI Pullup resistor R1

Microcontroller
1. Add the microcontroller, IC1
2. Add pullup resistors R4 and R2
3. Add decoupling capacitor C4
4. Solder in headers to the ICP
5. CHECK EVERYWHERE FOR SHORTS AGAIN

Programming, Part II

1. (Assuming everything is ready!) DO NOT APPLY EXTERNAL POWER. Plug in the ICSP.
- If there is a short, the PTC fuse should get very hot – disconnect quickly.
- Fix this condition before continuing! The PTC might take quite some time before resetting, anyway – you've got time.
2. Programming the microcontroller is a 2 – (maybe 3) – step process:
1. (Optional) Calibrate the ATTiny's oscillator. This is beyond the scope of this document, but one way to do it is with an oscilloscope and Pepas Labs' CalibrateATTiny85OSCCAL: https://github.com/pepaslabs/CalibrateATtiny85OSCCAL
2. Program VGATonic firmware to burn EEPROM: fonts, initial calibration for LTC6903
1. It's simple – in your IDE, remove the comment from the line ”//#define EEPROM_UPDATE 1 // Uncomment when you want to write EEPROM, otherwise leave this alone.”
2. If you calibrated the oscillator, change the character in OSCALSPEED from default 'K' in the file 'utilities.ino': ”eeprom_update_byte (( uint8_t *) OSCALSPEED, 'K' );”
3. Once the line is removed, upload the firmware from the Arduino IDE to the microcontroller over ICSP
3. Program VGATonic's non-EEPROM code.
1. Just add the comment back to the line
2. Once the line is added back, VGATonic will fix the font lookup and add all of the code to support the framebuffer and terminal emulator.
3. REMOVE POWER BEFORE CONTINUING

VGA Output Stage

1. Add the VGA Connector
2. Add VGA output resistors R5, R6, R7, R8, R9, R10, R11, R12, R13

External SPI Interface

1. Add male headers to P2, labels “SCK”, “MOSI”, “MISO” and “~CS”
2. Add SPI Pullup resistor R3

External Serial Interface

1. Add male headers to P1, labels “RX” and “TX”

Optional

For hardware hacking or alternative modes, these components might be useful!

1. Add the optional 'Wing' Style female headers in P8, P7, P10 and P9
2. Add the optional user switches to SW1
1. Add resistors R20, R21, R22
3. Add the RCA Output Stage
1. Solder in the RCA Jack
2. Add output resistors R14, R15, R16, R17, R18, R19

If you're sure there are no shorts (triple check it!), apply power! Assuming the fuse doesn't trip, try hooking up the VGA output.

A green screen means all the programming worked – congratulations! Try interfacing with VGATonic over Asynchronous Serial and/or SPI – that will be the final message on whether your VGATonic build was a successful one!

# About VGATonic and its Builder, PK!

If you're anything like me, you've got a bunch of dev boards and single board computers stored somewhere in your house.
That pile was getting pretty big when I got the idea for VGATonic –VGA output I could add to some of the headless parts I'd collected. Fortuitously, the Hackaday Prize 2014 was just kicking off – those two threads tied together, and VGATonic was born!
I finished a minimum viable project in 2014 – working 640x480 in 256 colors on an Arduino and an Intel Galileo in Arduino Mode - but didn't push for a product... let alone a completed project. Admittedly, my effort was weak – on the order of “I have proven it can be done.”... but no further.
Motivation waned for a while until I saw a soldered VGATonic on my desk a few weeks into the Hackaday Prize 2015 – and I sat down and wrote a Linux framebuffer driver for the Raspberry Pi. When I played Doom on VGATonic for the first time, the motivation came rushing back!
The rest, as the saying goes, is history.
2015 has been dedicated to bringing example graphics drivers to lots of new single board computers and microcontrollers, along with hardware acceleration, lower resolution modes, and lower bit depth modes. I also added lots of features to the microcontroller – and the all important asynchronous serial modes – which give out of the box framebuffer and terminal emulator support to (probably, but who can count?) thousands of parts made over the last 40 years!
As for me, I live in Silicon Valley and work as a software engineer. I've been at the same firm for the last seven years. I'm married with a not-yet-two-year-old daughter, and a dog my wife and I jokingly call our “son”. When I'm not working on hardware projects, I maintain a website at http://dqydj.net that includes lots of hacks of the software variety!

# Appendix

## VGATonic Escape Codes

VT52 Compatible Escape Codes

Hit escape, then hit the following character to execute the commands:

A - Move the cursor to beginning of line above.
B - Move the cursor to beginning of line below.
C - Move the cursor right by one.
D - Move the cursor left by one.
E - Clear the screen and place the cursor in the upper left corner. H - Move the cursor to the upper left corner.
I - Move the cursor to beginning of line above.
J - Erase all lines after our current line
K - Clear the current line from the current cursor position.
M - Delete the current line.
Y - 'Goto' Coordinate mode - first will change line number, then cursor position (both ASCII - 32) b - Byte after 'b' sets new foreground color.
c - Byte after 'c' sets new background color.
d - Erase all lines above current line.
e - Enable the cursor.
f - Disable the cursor.
l - Erase current line line and place the cursor at the beginning of the row. o - Erase the current line from the beginning to the current cursor.
p - Invert background and foreground color.
q - Invert background and foreground color.
Special VGATonic Only Escape Codes

% - Administrator Mode
W - 'W'rite framebuffer mode (pass through pixels from UART, 150 at a time)
Z - Send control character to VGATonic. (Position or Resolution or Bit Depth change)
m - Become 'm'aster of CPLD (Disable external SPI writes and put Microcontroller in control) r - 'r'elease CPLD (Allow external SPI writes)
s - 's'elect CPLD (Warn CPLD a new frame write is coming)
u - 'u'nselect CPLD (Inform CPLD current frame write is done)
Special VGATonic Only Administrator Escape Codes ( Esc-%-(code) )

< - 9600 Baud Serial Terminal (Default)
> - 38400 Baud Serial Terminal
+ - Add one to LTC6903 PLL Scaler
- - Subtract one from LTC6903 PLL Scaler
& - VGATonic default PLL Scaler, 0B01011110 | - Burn current PLL Scaler to EEPROM

## VGATonic Block Diagram


## High-Resolution PCB

Stars Mark Power/Ground: Black – Ground; Yellow - +3.3 Volts; Red - + 5 Volts

Only Apply Power to USB OR One +5V Pin, never both!

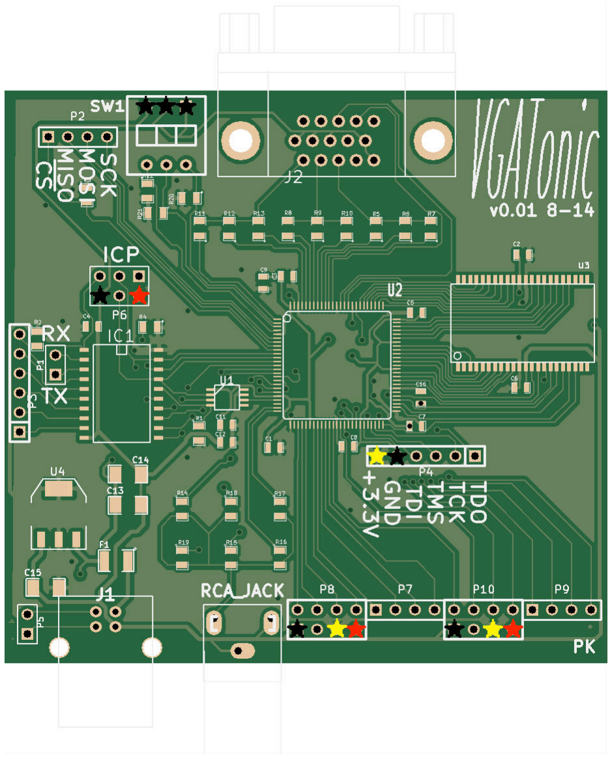
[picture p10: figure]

VGATonic Start Up Sequence

1. ATTiny 2313a microcontroller sends control bytes to LTC6903 Programmable Oscillator to set the Display Core Clock.
- With default firmware, this will be ~ 50.344 MHz, or almost exactly 2x the 640x480 VGA Clock of 25.175 MHz
2. Microcontroller grabs control of VGATonic's Display Core (VGATonic will ignore all external SPI writes)
1. Sets mode to 160x120 in 8 bit color
2. Draws a completely green screen and sets the font color if later needed
3. Microcontroller gives up control of the Display Core to the external SPI interface

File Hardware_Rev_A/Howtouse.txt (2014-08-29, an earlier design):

For this demo, I've made the protocol as basic as possible (but no simpler, right?):

1) Pull the chip select low.
2) Write pixels like this: R2R1R0 G2G1G0 B1B0 (where higher numbers are more significant for each pixel.)
3) That's it, seriously.

The only trick to be aware of?  Setting CS high then pulling it low again will reset the write counter to the upper left hand corner.  You can theoretically use this to skip full screen writes if you're only updating things near the top of the screen.

Don't wed yourself to this protocol though, we'll try to make something better in the final version.  But hey, good first effort, eh?

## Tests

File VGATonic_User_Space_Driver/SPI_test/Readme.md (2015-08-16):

This demo is meant for the Arduino Uno to show Hardware Acceleration on VGATonic.

Connect VGATonic's SCK to pin 13, VGATonic's MOSI to pin 11, and VGATonic's Chip Select to pin 9.  Then provide power.  The Arduino Uno will run at only 2 MHz SPI, but show how to skip to individual lines.

There is other code in here showing how to write and how to change resoutions and modes.

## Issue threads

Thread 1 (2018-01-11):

Low speed specs?

calphool, 2018-01-11:
Hi there, the docs for VGAtonic says that it supports anything that can talk SPI, I'm wondering what *minumum* speed would be?  In other words, what does it do if the SPI clock in is literally toggling at millisecond speeds?  Does it work, or does it flip out?  The reason I ask, is I'd like to use VGATonic as a graphics card for a breadboard 8-bit TTL-based computer (breadboard stuff) that I'm building with some high school kids as a learning exercise.  So, we could generate SPI signals, but they're going to be **slow**, and actually since we enable a "single step mode" for the CPU components, it could end up being *very very very* slow.

dqydj, 2018-01-13:
Interesting application!

I haven't tested a minimum speed, but my suspicion is for SPI that if your clock and data edges are clean you can go all the way down to DC. If you're single stepping off a button make sure you're filtering it properly. SPI is definitely the way to go not UART (where you can drop the speed but you'll still need to sustain the rate you pick).

Also, I'd be remiss if I didn't mention that RAiO makes an interesting chip, the RA8875, which drives 40-pin TTL displays with an SPI input. It's not quite VGA, but it might be an interesting option to evaluate as well. Adafruit has them on a breakout board: https://www.adafruit.com/product/1590

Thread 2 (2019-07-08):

Supplying chain

mchobby, 2019-07-08:
Hi,
it seems to be a very appealing project.
Would it be possible to have the board available as a Kit or pre-assembled ?

Kind regards,
Dominique

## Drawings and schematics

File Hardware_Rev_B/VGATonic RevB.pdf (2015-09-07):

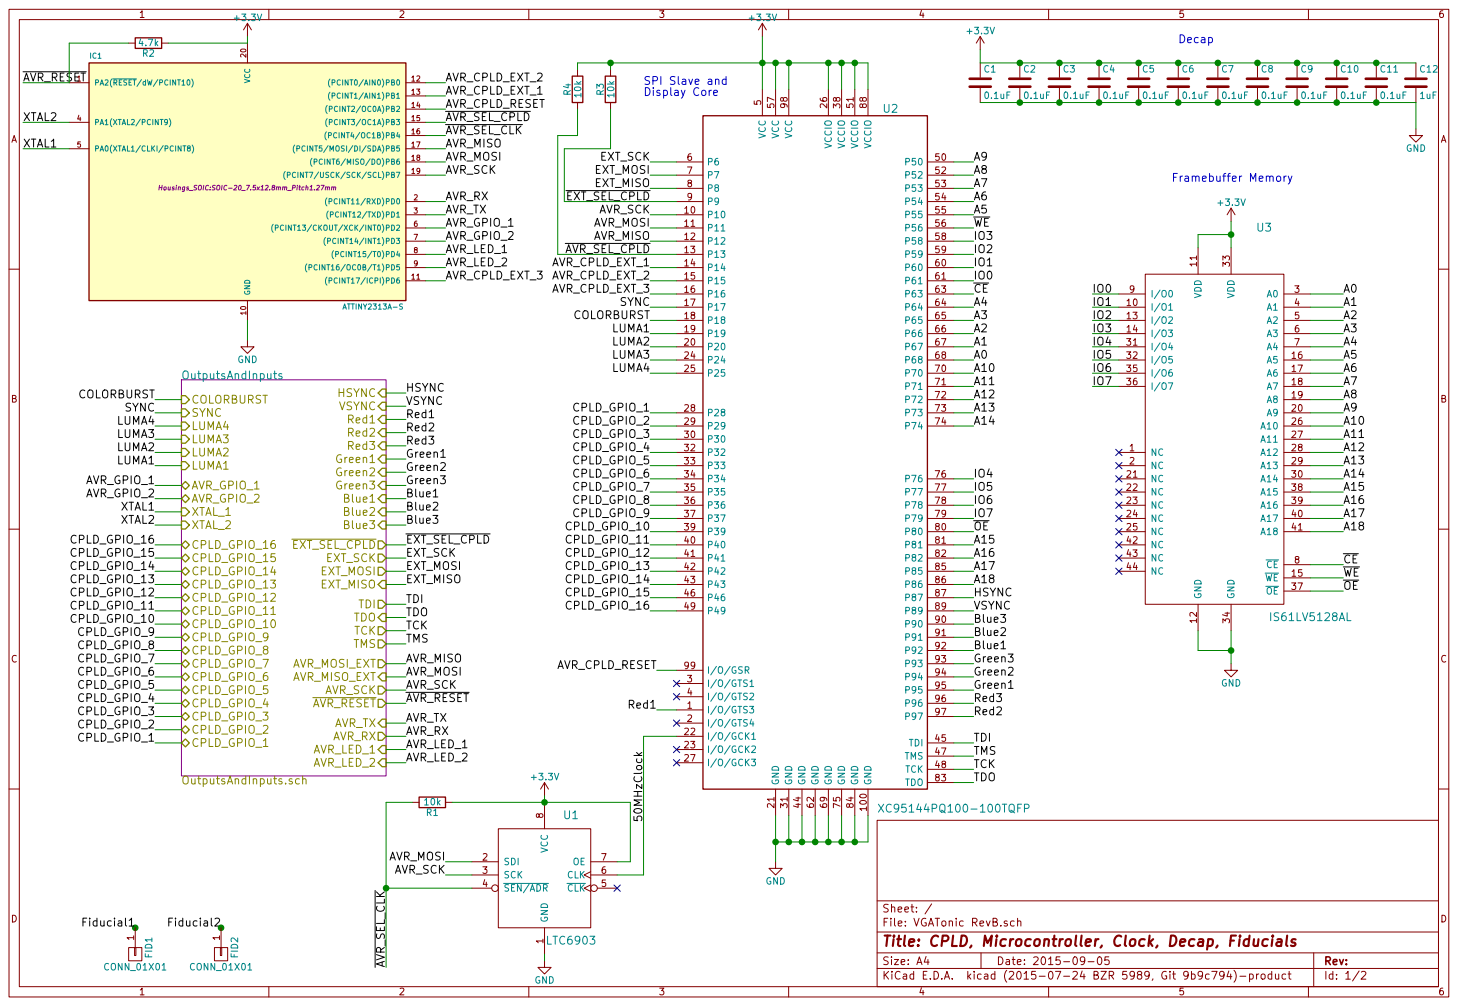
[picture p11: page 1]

1 SDI 2 SCK 3 SEN/ADR 4 CLK 5 CLK 6 OE 7 VCC

File: VGATonic RevB.sch Sheet: /
Id: 1/2 Title: CPLD, Microcontroller, Clock, Decap, Fiducials

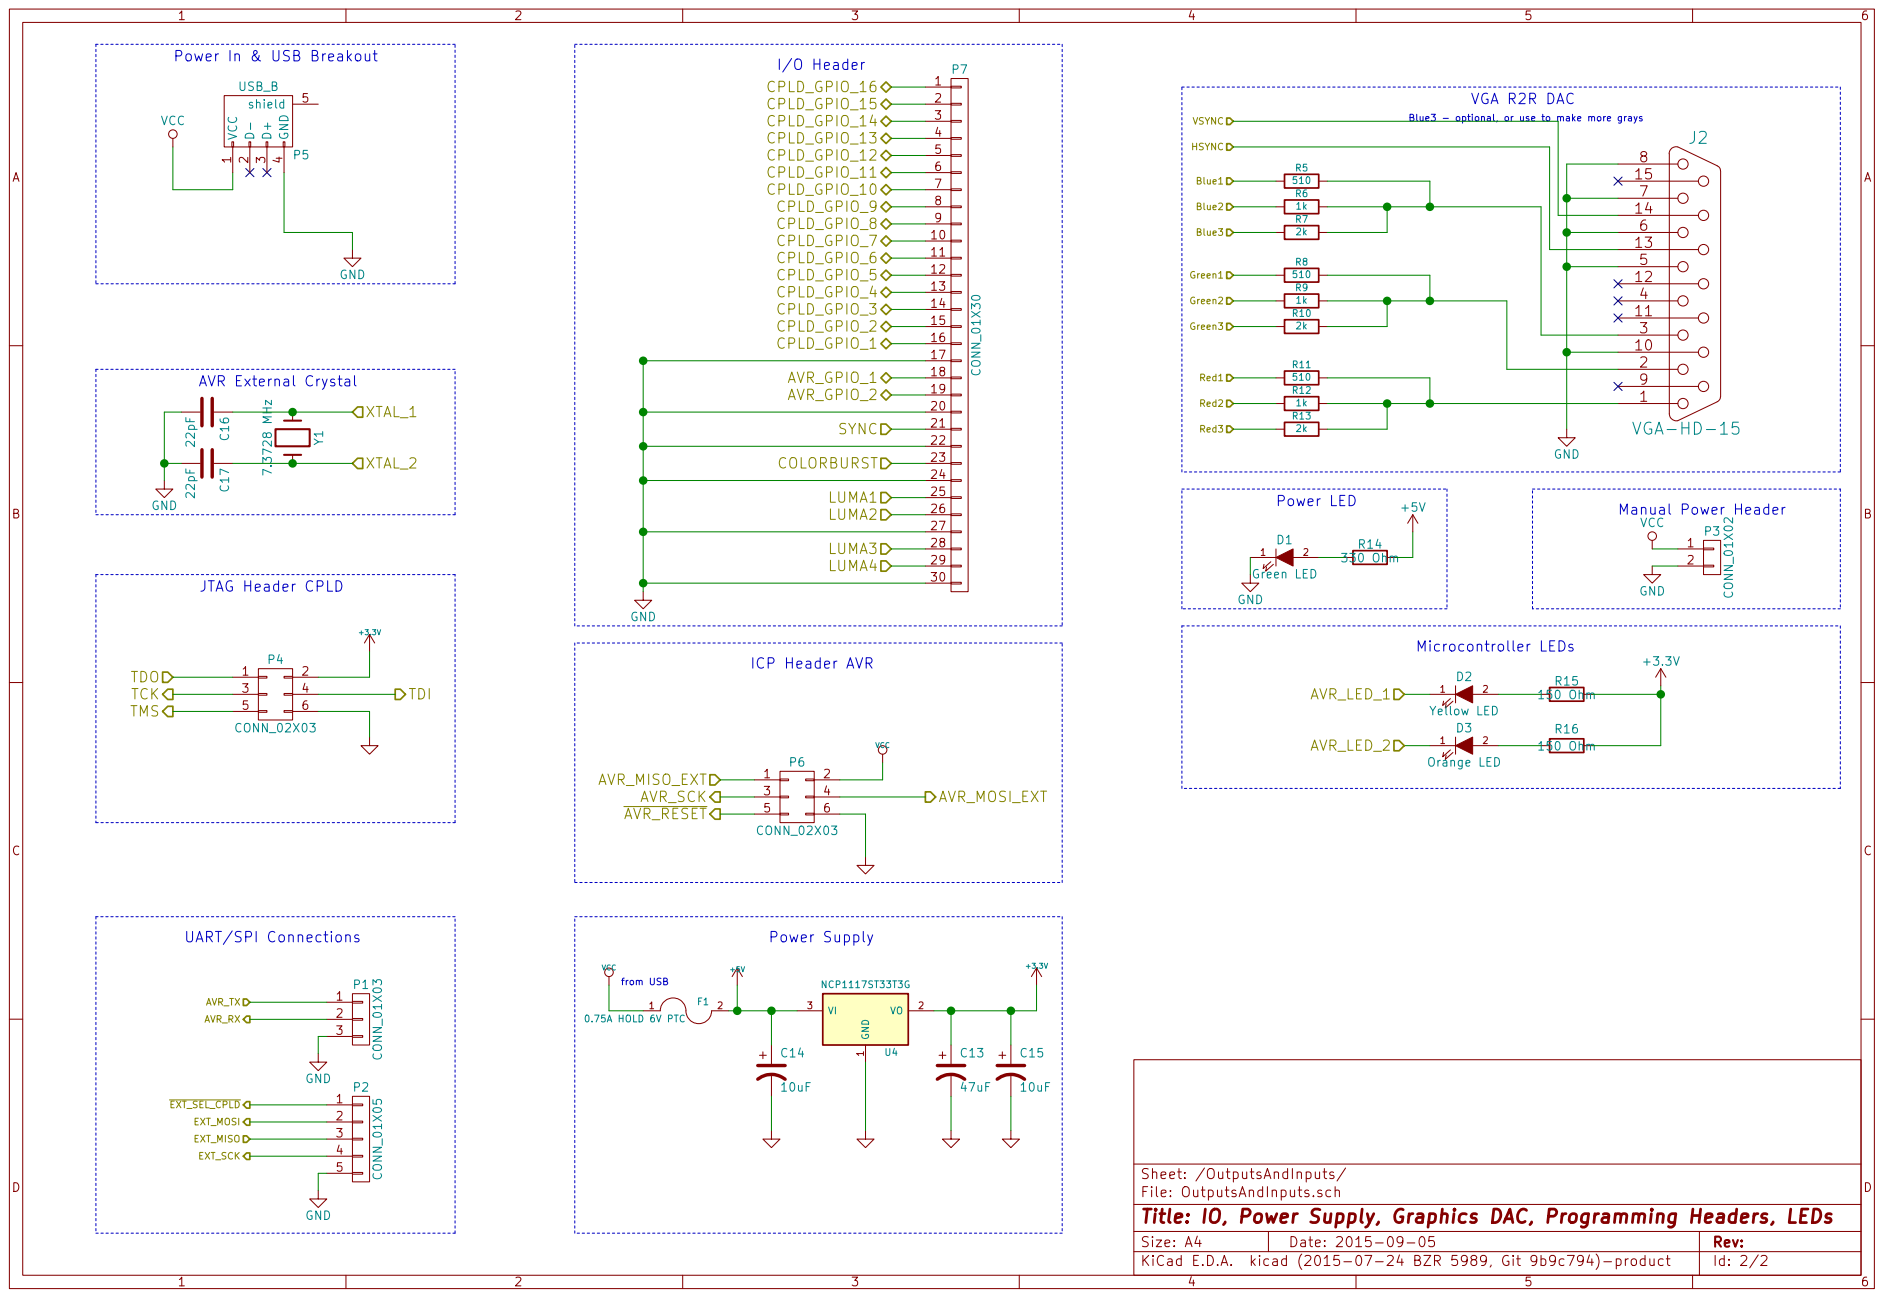
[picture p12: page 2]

AVR_GPIO_1 AVR_GPIO_2 20

Sheet: /OutputsAndInputs/
File: OutputsAndInputs.sch
Id: 2/2 Title: IO, Power Supply, Graphics DAC, Programming Headers, LEDs

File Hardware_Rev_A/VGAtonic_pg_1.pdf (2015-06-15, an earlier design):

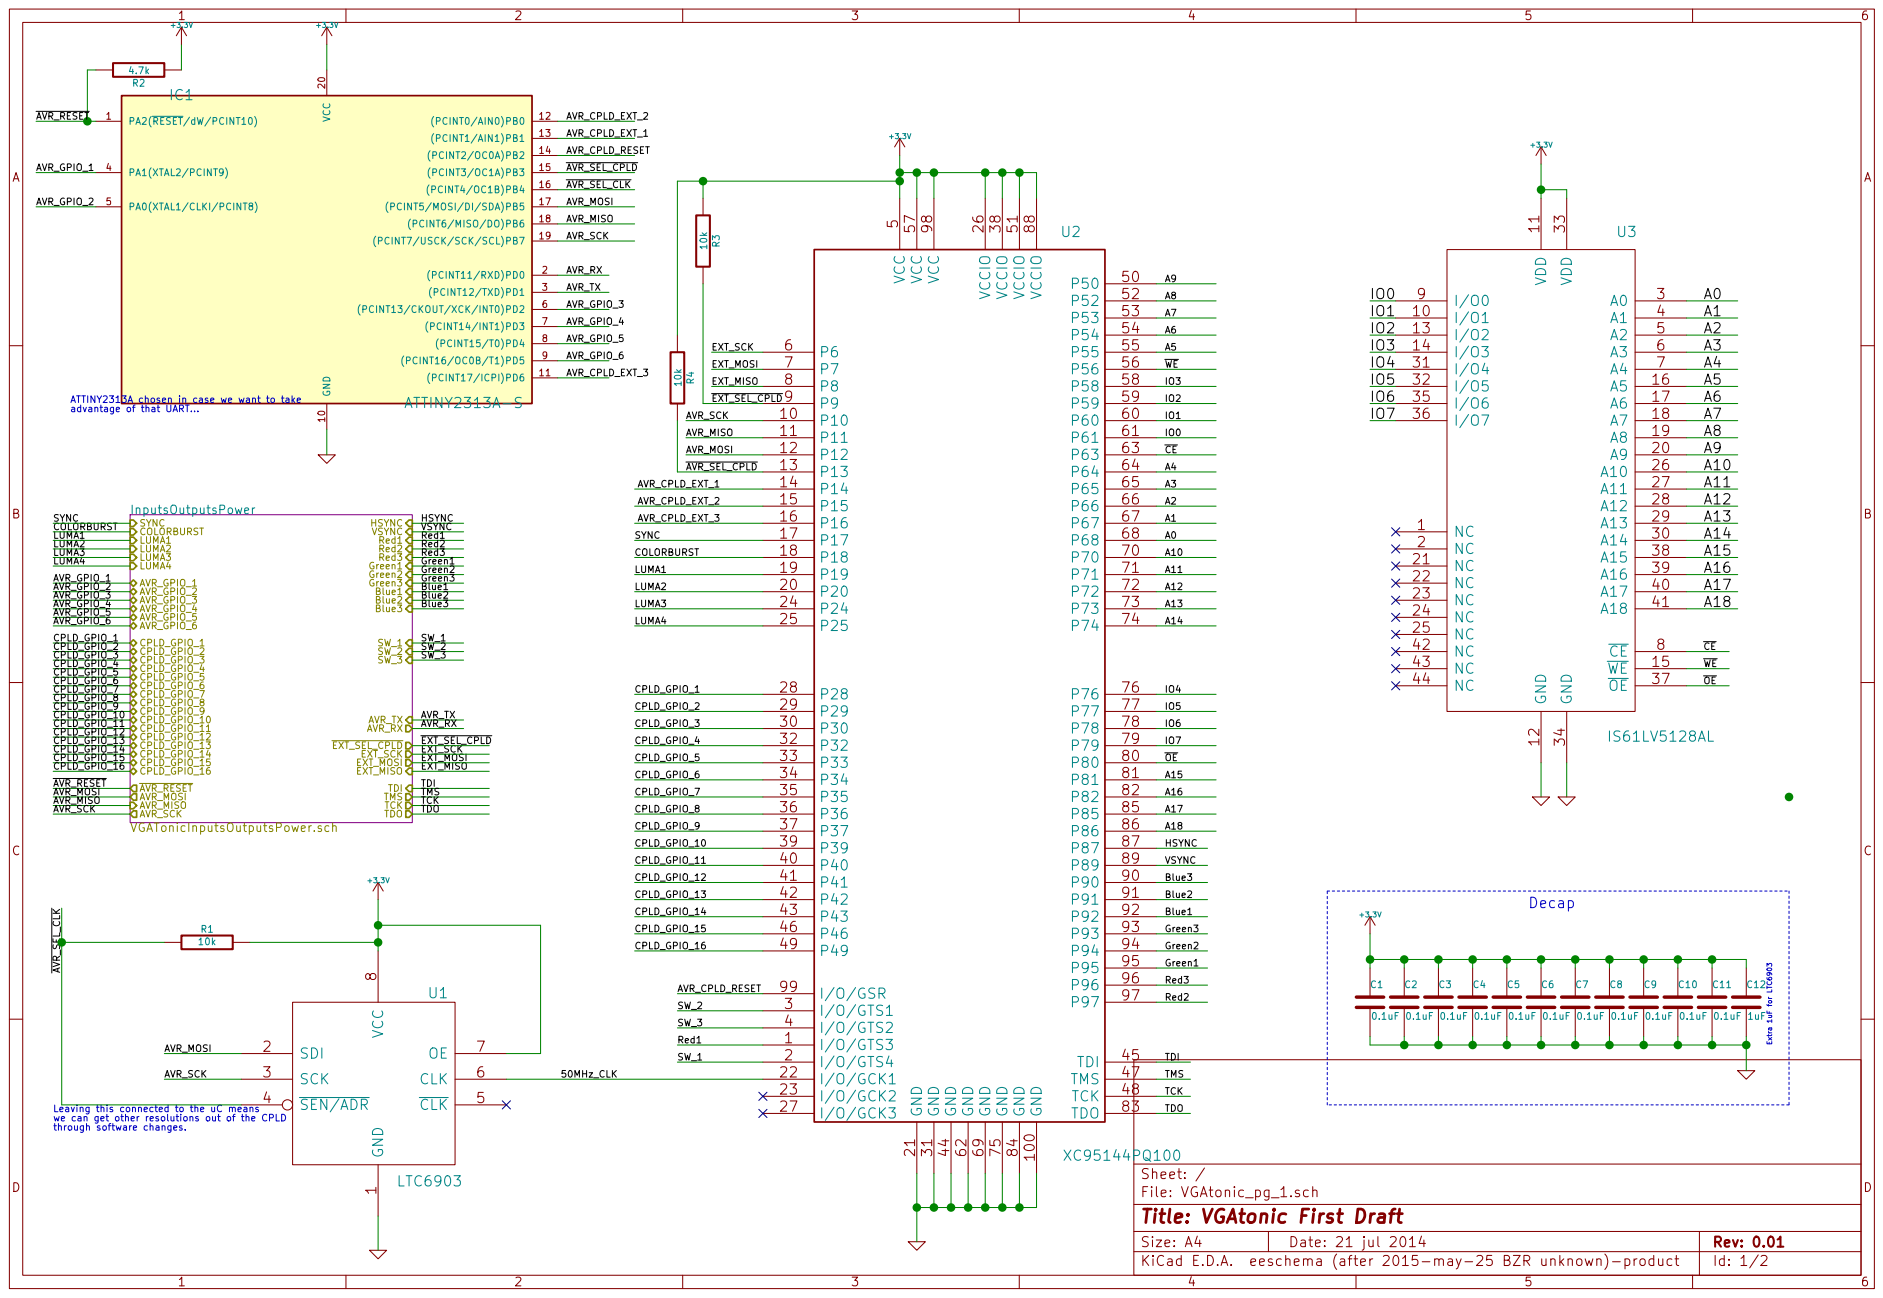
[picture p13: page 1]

ATTINY2313A chosen in case we want to take

1 SDI 2 SCK 3 SEN/ADR 4 CLK 5 CLK 6 OE 7 VCC

Leaving this connected to the uC means we can get other resolutions out of the CPLD
through software changes.

File: VGAtonic_pg_1.sch Sheet: /
Id: 1/2 Title: VGAtonic First Draft

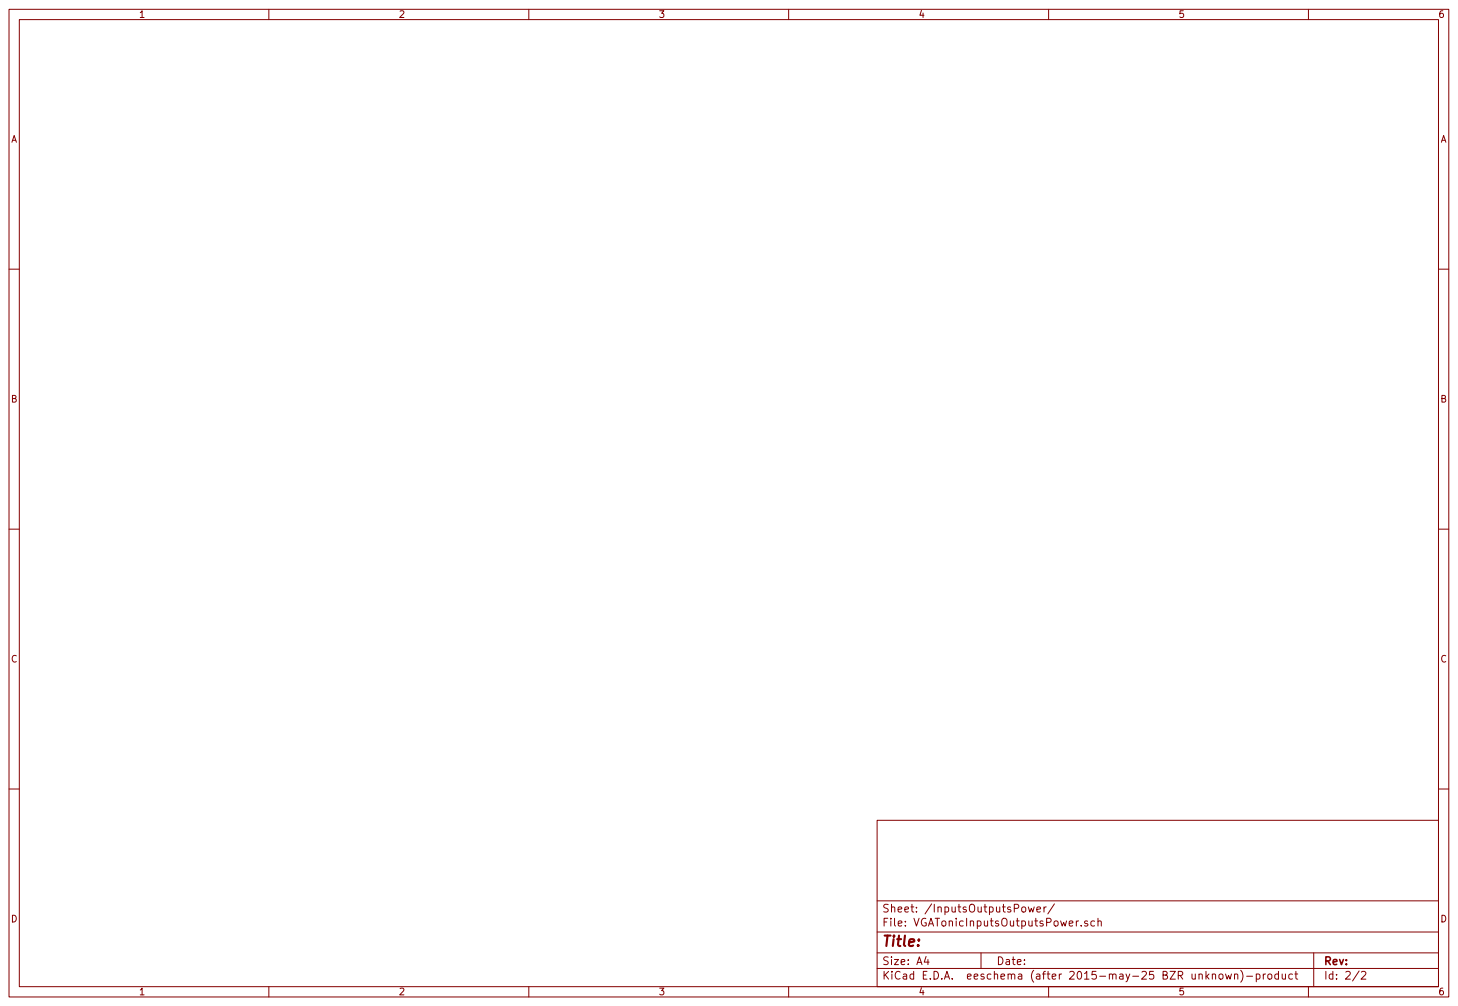
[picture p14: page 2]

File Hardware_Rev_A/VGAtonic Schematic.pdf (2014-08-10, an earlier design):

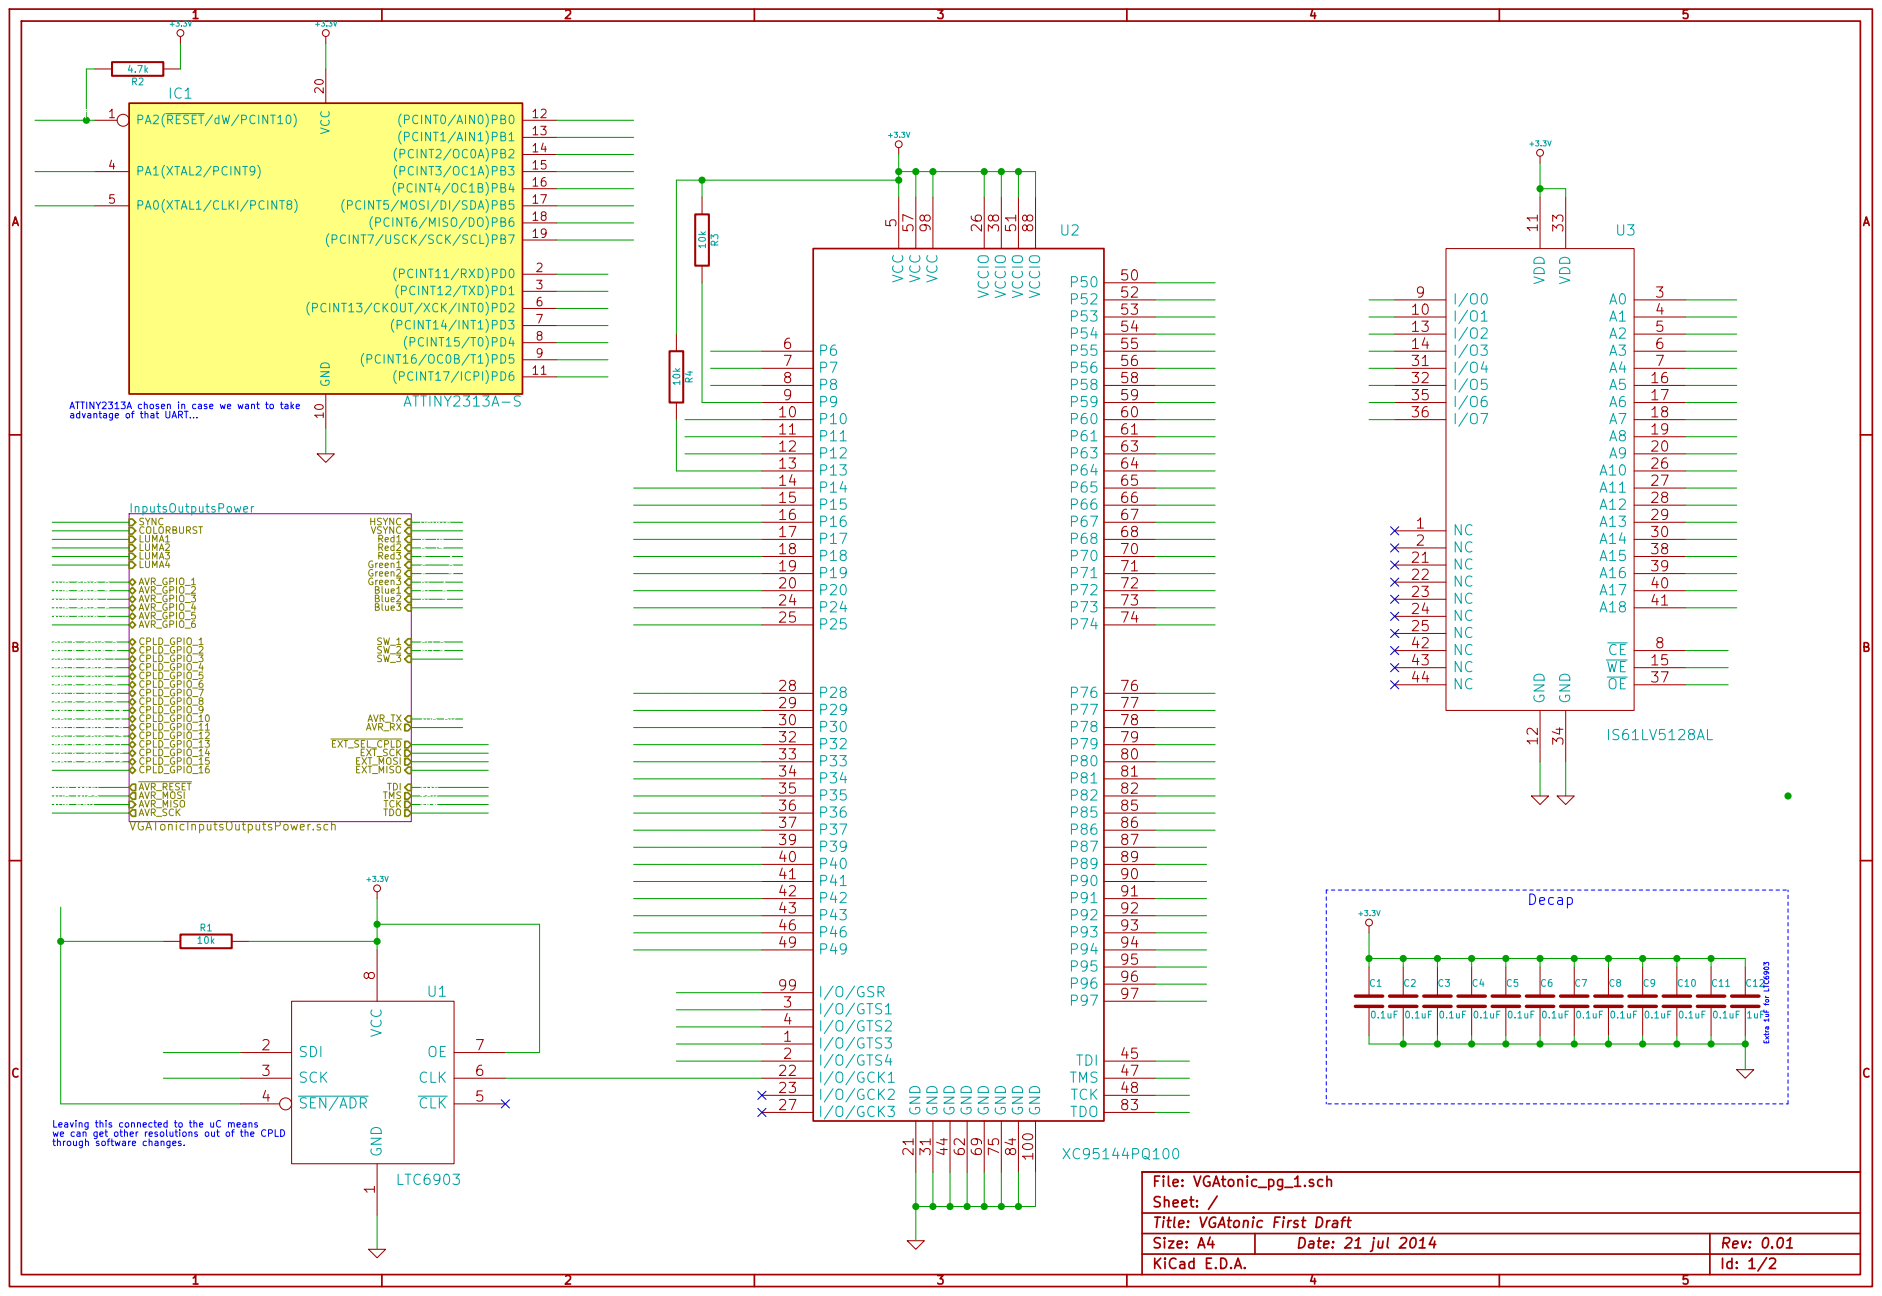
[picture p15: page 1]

ATTINY2313A chosen in case we want to take

1 SDI 2 SCK 3 SEN/ADR 4 CLK 5 CLK 6 OE 7 VCC

Leaving this connected to the uC means we can get other resolutions out of the CPLD
through software changes.

File: VGAtonic_pg_1.sch
Sheet: /
Title: VGAtonic First Draft
KiCad E.D.A.

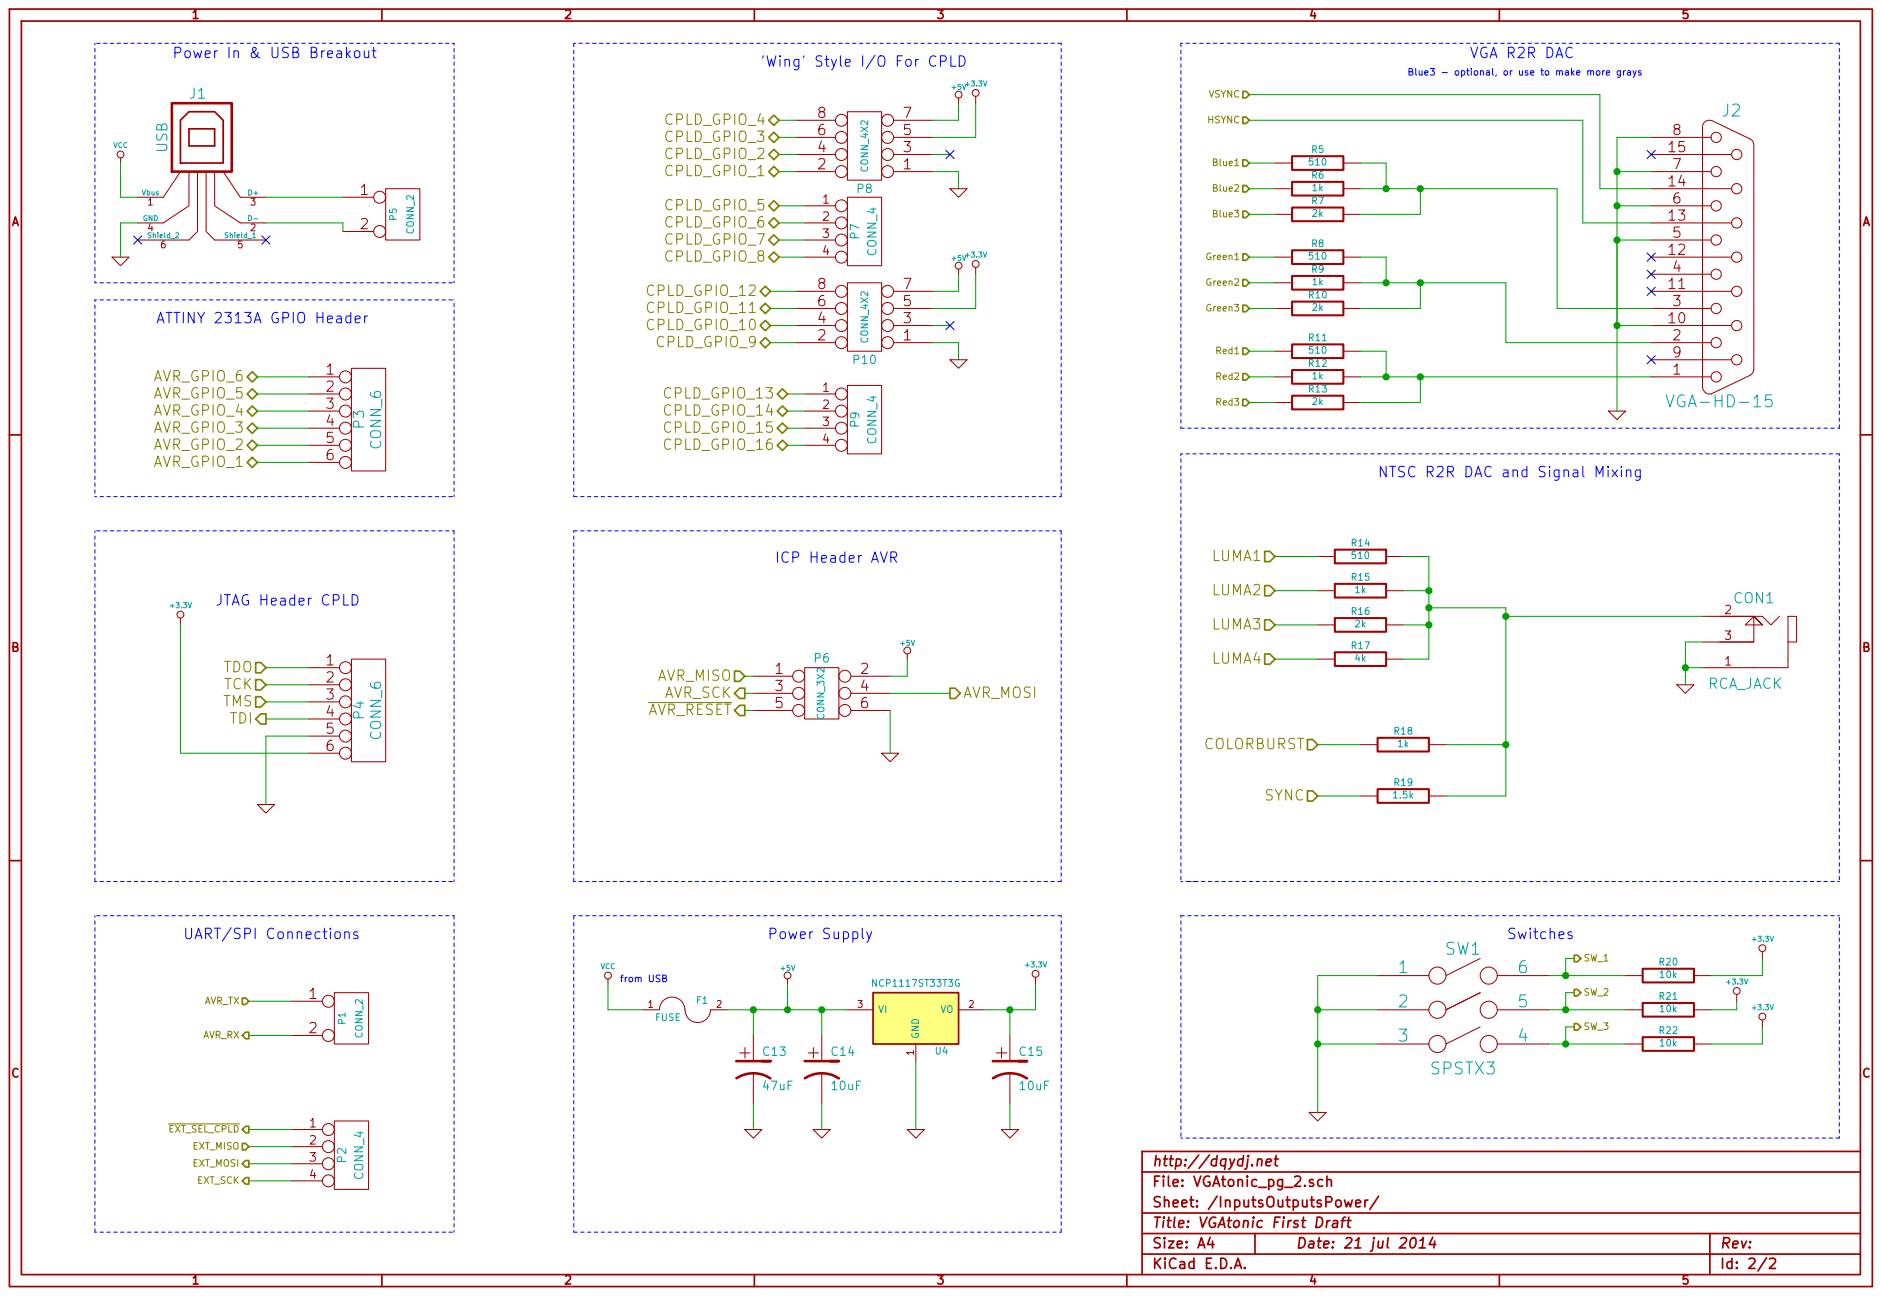
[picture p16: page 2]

Power In & USB Breakout

'Wing' Style I/O For CPLD

http://dqydj.net
File: VGAtonic_pg_2.sch
Sheet: /InputsOutputsPower/
Title: VGAtonic First Draft
KiCad E.D.A.

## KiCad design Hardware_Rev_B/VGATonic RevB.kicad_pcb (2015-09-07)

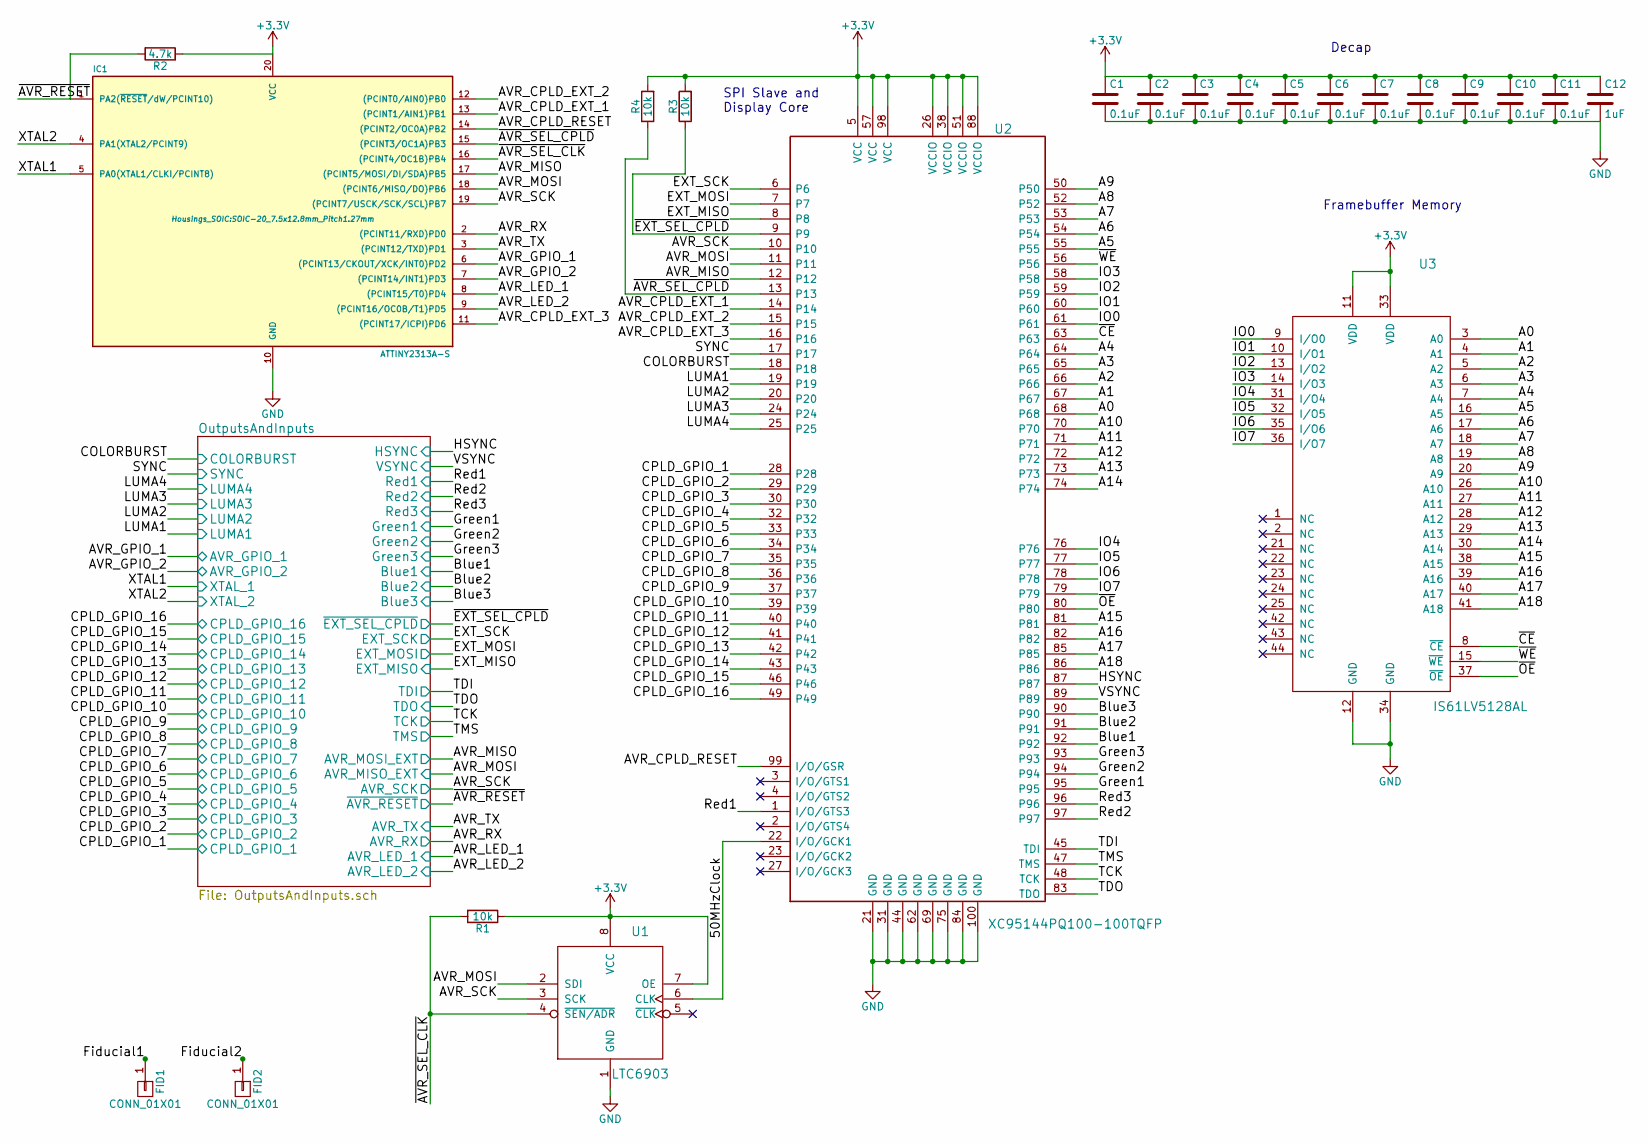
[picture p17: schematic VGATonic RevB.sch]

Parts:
C1, C2, C3, C4, C5, C6, C7, C8, C9, C10, C11: 0.1uF; C_0603
C12: 1uF; C_0603
FID1, FID2: CONN_01X01; Fiducial_1mm_Dia_2.54mm_Outer_CopperTop
IC1: ATTINY2313A-S; SOIC-20_7.5x12.8mm_Pitch1.27mm
R1, R3, R4: 10k; R_0805
R2: 4.7k; R_0805
U1: LTC6903; MSOP-8_3x3mm_Pitch0.65mm
U2: XC95144PQ100-100TQFP; TQFP-100_14x14mm_Pitch0.5mm
U3: IS61LV5128AL; tsop2-44

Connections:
+3V3: C1.1, C2.1, C3.1, C4.1, C5.1, C6.1, C7.1, C8.1, C9.1, C10.1, C11.1, C12.1, IC1.20 (VCC), R1.1, R2.1, R3.2, R4.2, U1.7 (OE), U1.8 (VCC), U2.5 (VCC), U2.26 (VCCIO), U2.38 (VCCIO), U2.51 (VCCIO), U2.57 (VCC), U2.88 (VCCIO), U2.98 (VCC), U3.11 (VDD), U3.33 (VDD); also elsewhere on the board
/50MHzClock: U1.6 (CLK), U2.22 (I/O/GCK1)
/A0: U2.68, U3.3 (A0)
/A1: U2.67, U3.4 (A1)
/A2: U2.66, U3.5 (A2)
/A3: U2.65, U3.6 (A3)
/A4: U2.64, U3.7 (A4)
/A5: U2.55, U3.16 (A5)
/A6: U2.54, U3.17 (A6)
/A7: U2.53, U3.18 (A7)
/A8: U2.52, U3.19 (A8)
/A9: U2.50, U3.20 (A9)
/A10: U2.70, U3.26 (A10)
/A11: U2.71, U3.27 (A11)
/A12: U2.72, U3.28 (A12)
/A13: U2.73, U3.29 (A13)
/A14: U2.74, U3.30 (A14)
/A15: U2.81, U3.38 (A15)
/A16: U2.82, U3.39 (A16)
/A17: U2.85, U3.40 (A17)
/A18: U2.86, U3.41 (A18)
/AVR_CPLD_EXT_1: IC1.13 ((PCINT1/AIN1)PB1), U2.14
/AVR_CPLD_EXT_2: IC1.12 ((PCINT0/AIN0)PB0), U2.15
/AVR_CPLD_EXT_3: IC1.11 ((PCINT17/ICPI)PD6), U2.16
/AVR_CPLD_RESET: IC1.14 ((PCINT2/OC0A)PB2), U2.99 (I/O/GSR)
/IO0: U2.61, U3.9 (I/O0)
/IO1: U2.60, U3.10 (I/O1)
/IO2: U2.59, U3.13 (I/O2)
/IO3: U2.58, U3.14 (I/O3)
/IO4: U2.76, U3.31 (I/O4)
/IO5: U2.77, U3.32 (I/O5)
/IO6: U2.78, U3.35 (I/O6)
/IO7: U2.79, U3.36 (I/O7)
/OutputsAndInputs/AVR_GPIO_1: IC1.6 ((PCINT13/CKOUT/XCK/INT0)PD2); also elsewhere on the board
/OutputsAndInputs/AVR_GPIO_2: IC1.7 ((PCINT14/INT1)PD3); also elsewhere on the board
/OutputsAndInputs/AVR_LED_1: IC1.8 ((PCINT15/T0)PD4); also elsewhere on the board
/OutputsAndInputs/AVR_LED_2: IC1.9 ((PCINT16/OC0B/T1)PD5); also elsewhere on the board
/OutputsAndInputs/AVR_MISO_EXT: IC1.18 ((PCINT6/MISO/DO)PB6), U1.2 (SDI), U2.11; also elsewhere on the board
/OutputsAndInputs/AVR_MOSI_EXT: IC1.17 ((PCINT5/MOSI/DI/SDA)PB5), U2.12; also elsewhere on the board
/OutputsAndInputs/AVR_RX: IC1.2 ((PCINT11/RXD)PD0); also elsewhere on the board
/OutputsAndInputs/AVR_SCK: IC1.19 ((PCINT7/USCK/SCK/SCL)PB7), U1.3 (SCK), U2.10; also elsewhere on the board
/OutputsAndInputs/AVR_TX: IC1.3 ((PCINT12/TXD)PD1); also elsewhere on the board
/OutputsAndInputs/Blue1: U2.92; also elsewhere on the board
/OutputsAndInputs/Blue2: U2.91; also elsewhere on the board
/OutputsAndInputs/Blue3: U2.90; also elsewhere on the board
/OutputsAndInputs/COLORBURST: U2.18; also elsewhere on the board
/OutputsAndInputs/CPLD_GPIO_1: U2.28; also elsewhere on the board
/OutputsAndInputs/CPLD_GPIO_2: U2.29; also elsewhere on the board
/OutputsAndInputs/CPLD_GPIO_3: U2.30; also elsewhere on the board
/OutputsAndInputs/CPLD_GPIO_4: U2.32; also elsewhere on the board
/OutputsAndInputs/CPLD_GPIO_5: U2.33; also elsewhere on the board
/OutputsAndInputs/CPLD_GPIO_6: U2.34; also elsewhere on the board
/OutputsAndInputs/CPLD_GPIO_7: U2.35; also elsewhere on the board
/OutputsAndInputs/CPLD_GPIO_8: U2.36; also elsewhere on the board
/OutputsAndInputs/CPLD_GPIO_9: U2.37; also elsewhere on the board
/OutputsAndInputs/CPLD_GPIO_10: U2.39; also elsewhere on the board
/OutputsAndInputs/CPLD_GPIO_11: U2.40; also elsewhere on the board
/OutputsAndInputs/CPLD_GPIO_12: U2.41; also elsewhere on the board
/OutputsAndInputs/CPLD_GPIO_13: U2.42; also elsewhere on the board
/OutputsAndInputs/CPLD_GPIO_14: U2.43; also elsewhere on the board
/OutputsAndInputs/CPLD_GPIO_15: U2.46; also elsewhere on the board
/OutputsAndInputs/CPLD_GPIO_16: U2.49; also elsewhere on the board
/OutputsAndInputs/EXT_MISO: U2.8; also elsewhere on the board
/OutputsAndInputs/EXT_MOSI: U2.7; also elsewhere on the board
/OutputsAndInputs/EXT_SCK: U2.6; also elsewhere on the board
/OutputsAndInputs/Green1: U2.95; also elsewhere on the board
/OutputsAndInputs/Green2: U2.94; also elsewhere on the board
/OutputsAndInputs/Green3: U2.93; also elsewhere on the board
/OutputsAndInputs/HSYNC: U2.87; also elsewhere on the board
/OutputsAndInputs/LUMA1: U2.19; also elsewhere on the board
/OutputsAndInputs/LUMA2: U2.20; also elsewhere on the board
/OutputsAndInputs/LUMA3: U2.24; also elsewhere on the board
/OutputsAndInputs/LUMA4: U2.25; also elsewhere on the board
/OutputsAndInputs/Red1: U2.1 (I/O/GTS3); also elsewhere on the board
/OutputsAndInputs/Red2: U2.97; also elsewhere on the board
/OutputsAndInputs/Red3: U2.96; also elsewhere on the board
/OutputsAndInputs/SYNC: U2.17; also elsewhere on the board
/OutputsAndInputs/TCK: U2.48 (TCK); also elsewhere on the board
/OutputsAndInputs/TDI: U2.45 (TDI); also elsewhere on the board
/OutputsAndInputs/TDO: U2.83 (TDO); also elsewhere on the board
/OutputsAndInputs/TMS: U2.47 (TMS); also elsewhere on the board
/OutputsAndInputs/VSYNC: U2.89; also elsewhere on the board
/OutputsAndInputs/XTAL_1: IC1.5 (PA0(XTAL1/CLKI/PCINT8)); also elsewhere on the board
/OutputsAndInputs/XTAL_2: IC1.4 (PA1(XTAL2/PCINT9)); also elsewhere on the board
/OutputsAndInputs/~AVR_RESET: IC1.1 (PA2(~RESET~/dW/PCINT10)), R2.2; also elsewhere on the board
/OutputsAndInputs/~EXT_SEL_CPLD: R3.1, U2.9; also elsewhere on the board
/~AVR_SEL_CLK: IC1.16 ((PCINT4/OC1B)PB4), R1.2, U1.4 (~SEN/ADR)
/~AVR_SEL_CPLD: IC1.15 ((PCINT3/OC1A)PB3), R4.1, U2.13
/~CE: U2.63, U3.8 (~CE)
/~OE: U2.80, U3.37 (~OE)
/~WE: U2.56, U3.15 (~WE)
GND: C1.2, C2.2, C3.2, C4.2, C5.2, C6.2, C7.2, C8.2, C9.2, C10.2, C11.2, C12.2, IC1.10 (GND), U1.1 (GND), U2.21 (GND), U2.31 (GND), U2.44 (GND), U2.62 (GND), U2.69 (GND), U2.75 (GND), U2.84 (GND), U2.100 (GND), U3.12 (GND), U3.34 (GND); also elsewhere on the board

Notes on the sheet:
Decap
Framebuffer Memory
SPI Slave and Display Core

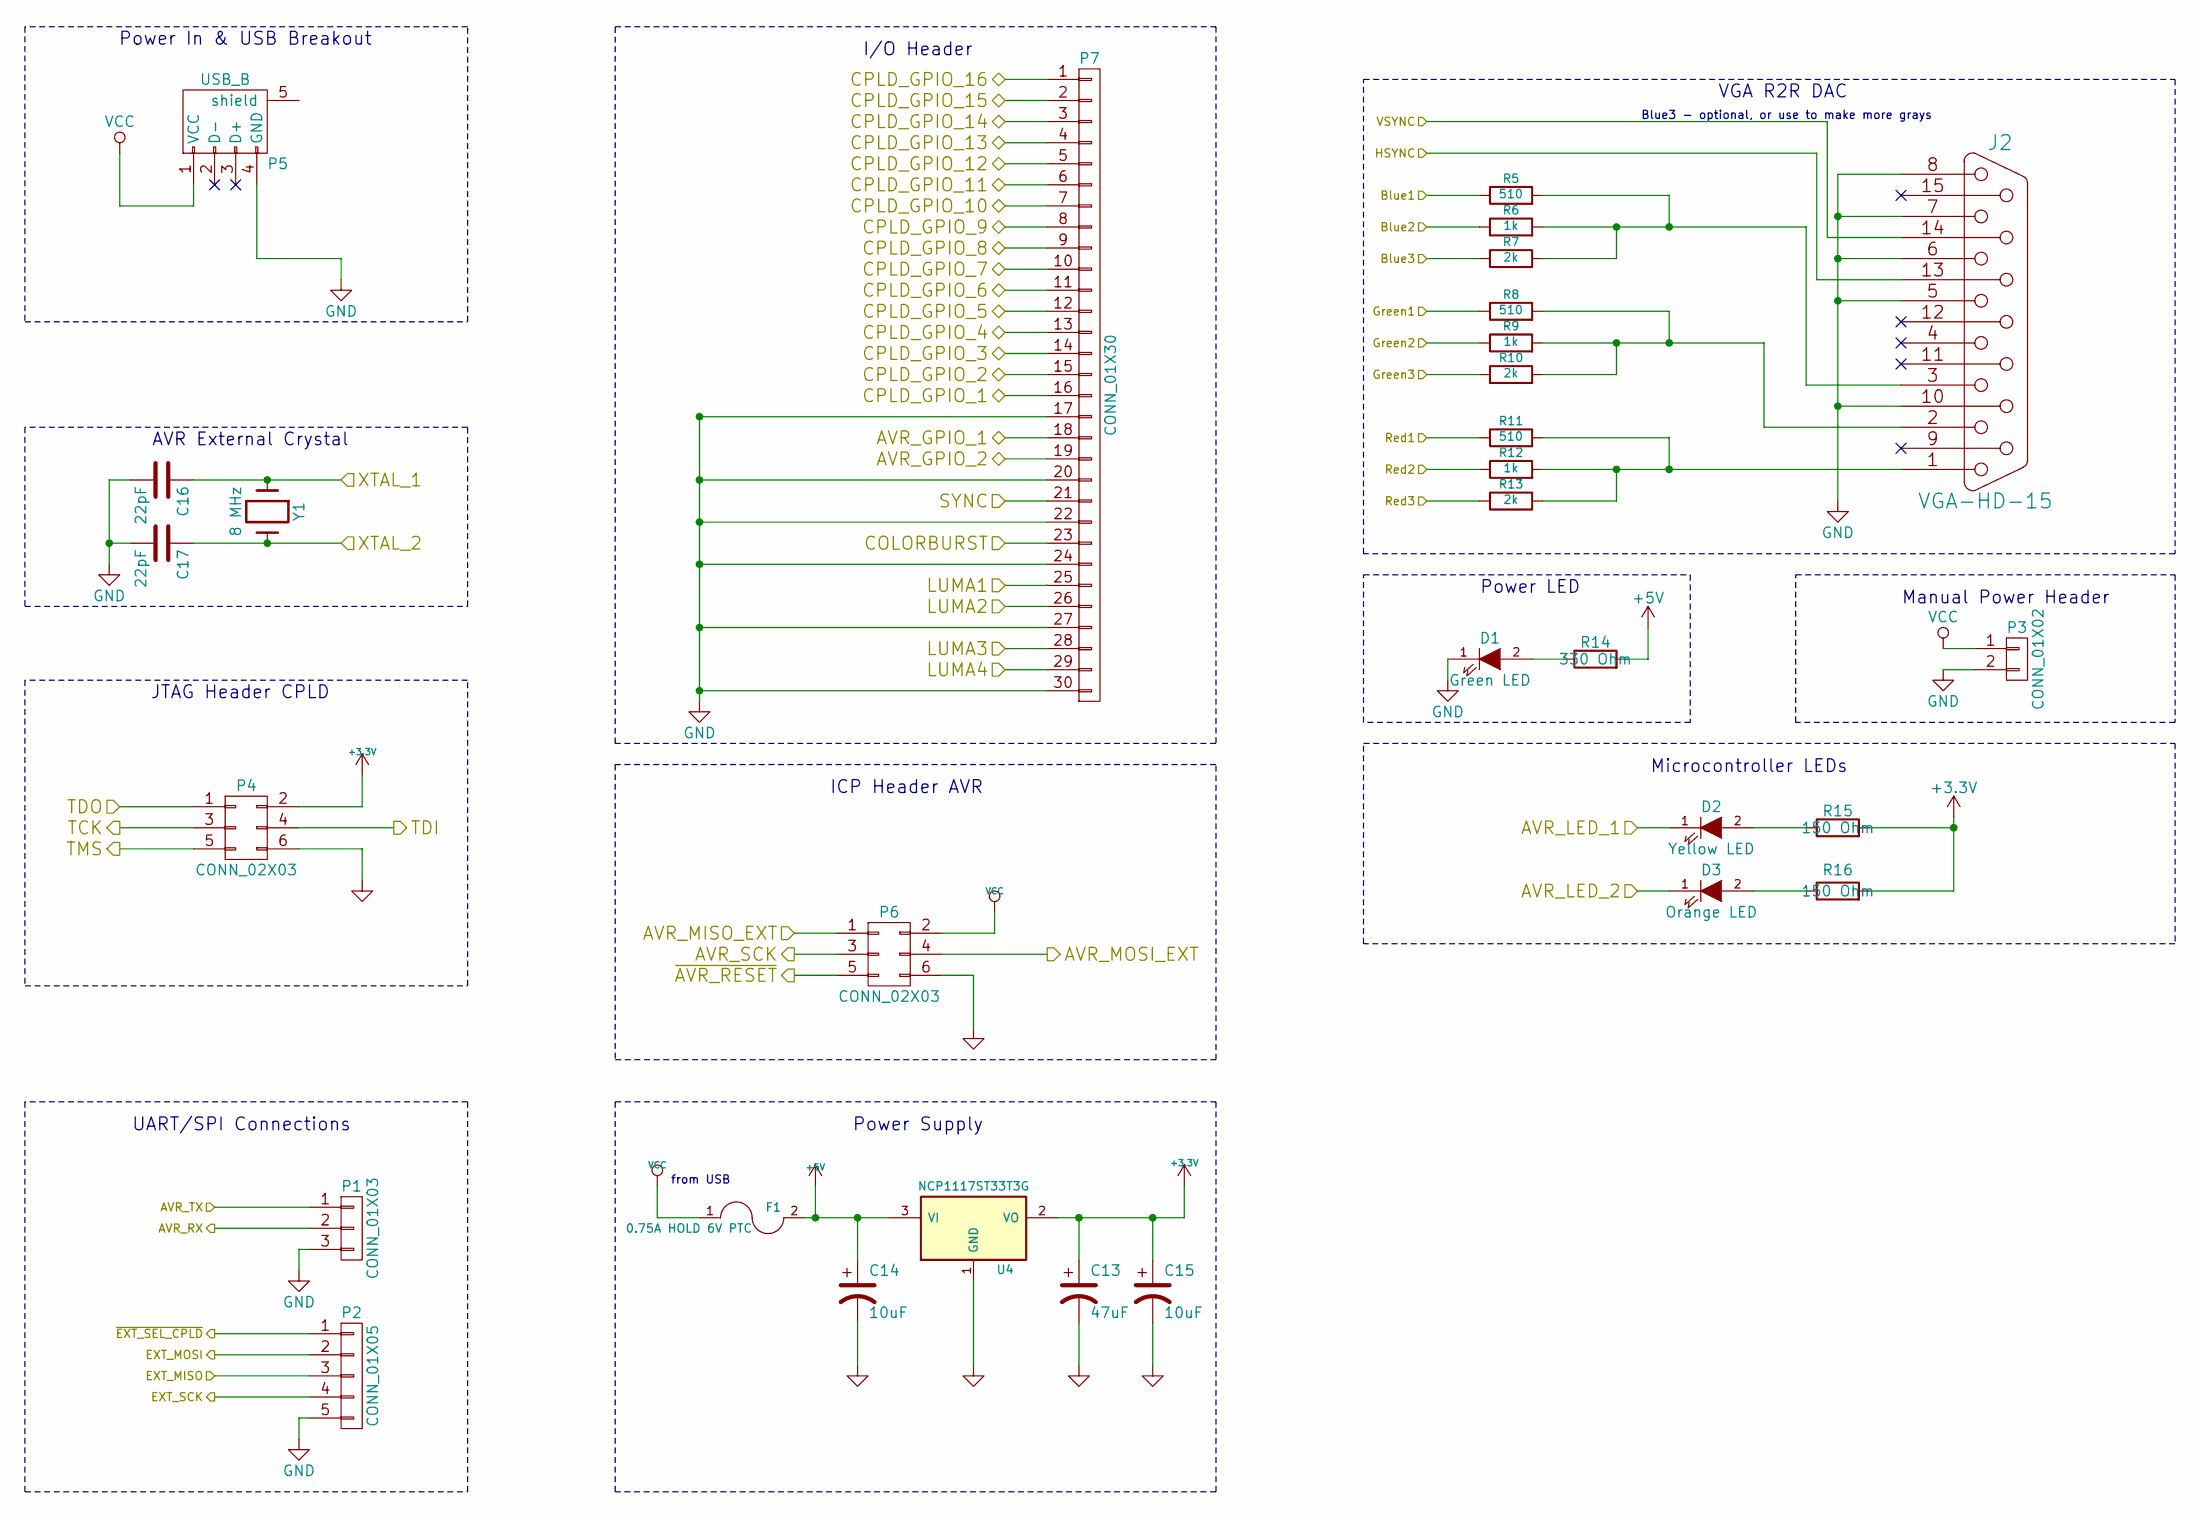
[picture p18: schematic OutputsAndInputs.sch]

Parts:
C13: 47uF; SMD-1206_Pol
C14, C15: 10uF; SMD-1206_Pol
C16, C17: 22pF; C_0603
D1: Green LED; LED-0603
D2: Yellow LED; LED-0603
D3: Orange LED; LED-0603
F1: 0.75A HOLD 6V PTC; R_1210
J2: VGA-HD-15; HD15_B-HD15F
P1: CONN_01X03; Pin_Header_Straight_1x03
P2: CONN_01X05; Pin_Header_Straight_1x05
P3: CONN_01X02; Pin_Header_Straight_1x02
P4, P6: CONN_02X03; Pin_Header_Straight_2x03
P5: USB_B
P7: CONN_01X30; DF40C-30DS-0.4V
R5, R8, R11: 510; R_0805
R6, R9, R12: 1k; R_0805
R7, R10, R13: 2k; R_0805
R14: 330 Ohm; R_0805
R15, R16: 150 Ohm; R_0805
U4: NCP1117ST33T3G; SOT223_PWR
Y1: 8 MHz; HC49_sm

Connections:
+3V3: C13.1, C15.1, P4.2, R15.2, R16.2, U4.2 (VO); also elsewhere on the board
+5V: C14.1, F1.2, R14.2, U4.3 (VI)
/OutputsAndInputs/AVR_GPIO_1: P7.18; also elsewhere on the board
/OutputsAndInputs/AVR_GPIO_2: P7.19; also elsewhere on the board
/OutputsAndInputs/AVR_LED_1: D2.1 (K); also elsewhere on the board
/OutputsAndInputs/AVR_LED_2: D3.1 (K); also elsewhere on the board
/OutputsAndInputs/AVR_MISO_EXT: P6.1; also elsewhere on the board
/OutputsAndInputs/AVR_MOSI_EXT: P6.4; also elsewhere on the board
/OutputsAndInputs/AVR_RX: P1.2; also elsewhere on the board
/OutputsAndInputs/AVR_SCK: P6.3; also elsewhere on the board
/OutputsAndInputs/AVR_TX: P1.1; also elsewhere on the board
/OutputsAndInputs/Blue1: R5.1; also elsewhere on the board
/OutputsAndInputs/Blue2: R6.1; also elsewhere on the board
/OutputsAndInputs/Blue3: R7.1; also elsewhere on the board
/OutputsAndInputs/COLORBURST: P7.23; also elsewhere on the board
/OutputsAndInputs/CPLD_GPIO_1: P7.16; also elsewhere on the board
/OutputsAndInputs/CPLD_GPIO_2: P7.15; also elsewhere on the board
/OutputsAndInputs/CPLD_GPIO_3: P7.14; also elsewhere on the board
/OutputsAndInputs/CPLD_GPIO_4: P7.13; also elsewhere on the board
/OutputsAndInputs/CPLD_GPIO_5: P7.12; also elsewhere on the board
/OutputsAndInputs/CPLD_GPIO_6: P7.11; also elsewhere on the board
/OutputsAndInputs/CPLD_GPIO_7: P7.10; also elsewhere on the board
/OutputsAndInputs/CPLD_GPIO_8: P7.9; also elsewhere on the board
/OutputsAndInputs/CPLD_GPIO_9: P7.8; also elsewhere on the board
/OutputsAndInputs/CPLD_GPIO_10: P7.7; also elsewhere on the board
/OutputsAndInputs/CPLD_GPIO_11: P7.6; also elsewhere on the board
/OutputsAndInputs/CPLD_GPIO_12: P7.5; also elsewhere on the board
/OutputsAndInputs/CPLD_GPIO_13: P7.4; also elsewhere on the board
/OutputsAndInputs/CPLD_GPIO_14: P7.3; also elsewhere on the board
/OutputsAndInputs/CPLD_GPIO_15: P7.2; also elsewhere on the board
/OutputsAndInputs/CPLD_GPIO_16: P7.1; also elsewhere on the board
/OutputsAndInputs/EXT_MISO: P2.3; also elsewhere on the board
/OutputsAndInputs/EXT_MOSI: P2.2; also elsewhere on the board
/OutputsAndInputs/EXT_SCK: P2.4; also elsewhere on the board
/OutputsAndInputs/Green1: R8.1; also elsewhere on the board
/OutputsAndInputs/Green2: R9.1; also elsewhere on the board
/OutputsAndInputs/Green3: R10.1; also elsewhere on the board
/OutputsAndInputs/HSYNC: J2.13; also elsewhere on the board
/OutputsAndInputs/LUMA1: P7.25; also elsewhere on the board
/OutputsAndInputs/LUMA2: P7.26; also elsewhere on the board
/OutputsAndInputs/LUMA3: P7.28; also elsewhere on the board
/OutputsAndInputs/LUMA4: P7.29; also elsewhere on the board
/OutputsAndInputs/Red1: R11.1; also elsewhere on the board
/OutputsAndInputs/Red2: R12.1; also elsewhere on the board
/OutputsAndInputs/Red3: R13.1; also elsewhere on the board
/OutputsAndInputs/SYNC: P7.21; also elsewhere on the board
/OutputsAndInputs/TCK: P4.3; also elsewhere on the board
/OutputsAndInputs/TDI: P4.4; also elsewhere on the board
/OutputsAndInputs/TDO: P4.1; also elsewhere on the board
/OutputsAndInputs/TMS: P4.5; also elsewhere on the board
/OutputsAndInputs/VSYNC: J2.14; also elsewhere on the board
/OutputsAndInputs/XTAL_1: C16.1, Y1.1; also elsewhere on the board
/OutputsAndInputs/XTAL_2: C17.1, Y1.2; also elsewhere on the board
/OutputsAndInputs/~AVR_RESET: P6.5; also elsewhere on the board
/OutputsAndInputs/~EXT_SEL_CPLD: P2.1; also elsewhere on the board
GND: C13.2, C14.2, C15.2, C16.2, C17.2, D1.1 (K), J2.5, J2.6, J2.7, J2.8, J2.10, P1.3, P2.5, P3.2, P4.6, P5.4 (GND), P6.6, P7.17, P7.20, P7.22, P7.24, P7.27, P7.30, U4.1 (GND); also elsewhere on the board
unnamed: D1.2 (A), R14.1
unnamed: D2.2 (A), R15.1
unnamed: D3.2 (A), R16.1
unnamed: J2.1, R11.2, R12.2, R13.2
unnamed: J2.2, R8.2, R9.2, R10.2
unnamed: J2.3, R5.2, R6.2, R7.2
VCC: F1.1, P3.1, P5.1 (VCC), P6.2

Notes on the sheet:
VGA R2R DAC
Blue3 - optional, or use to make more grays
Power In & USB Breakout
JTAG Header CPLD
ICP Header AVR
I/O Header
Power Supply
from USB
UART/SPI Connections
AVR External Crystal
Manual Power Header
Power LED
Microcontroller LEDs

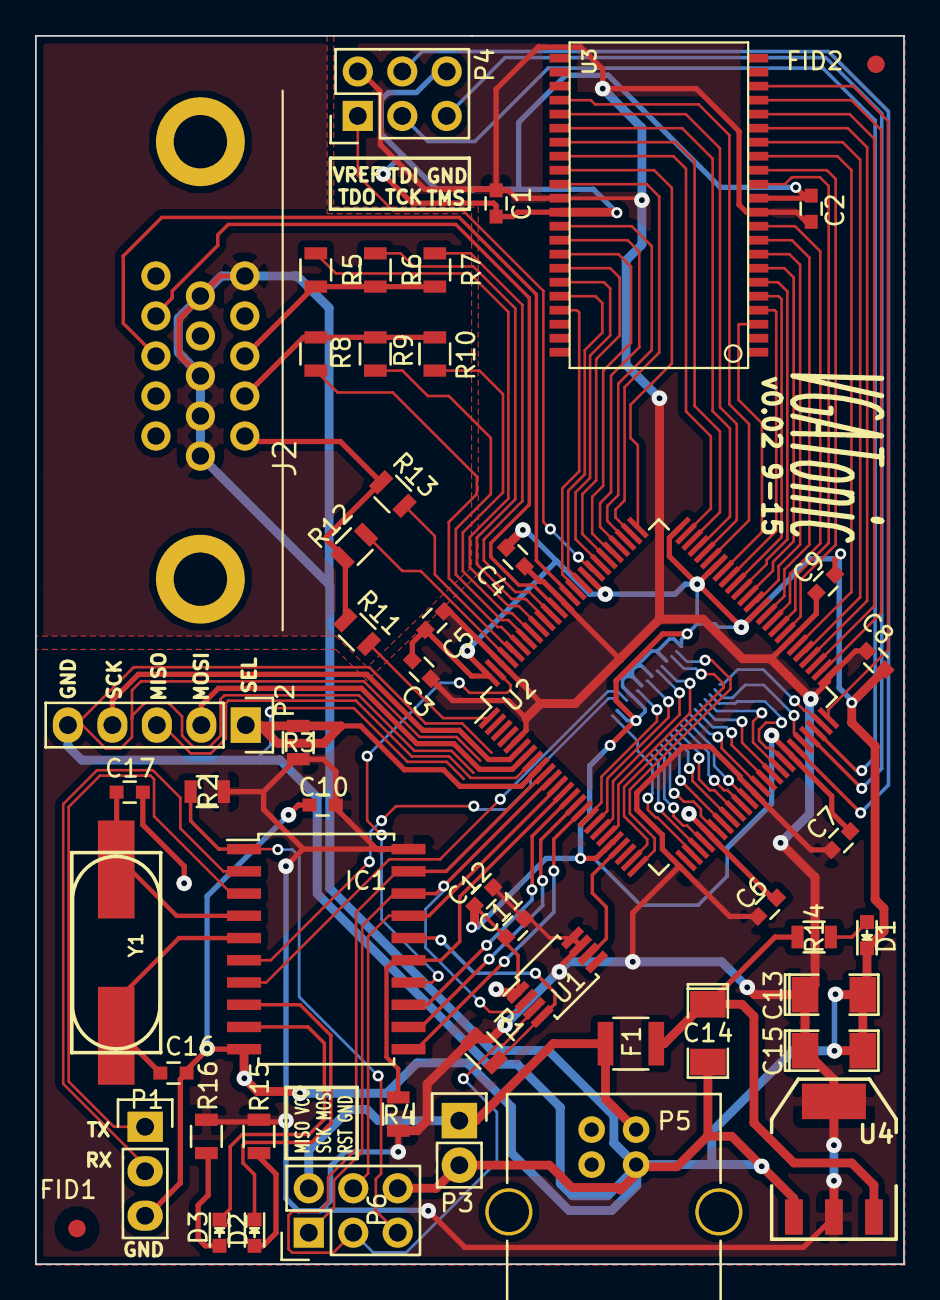
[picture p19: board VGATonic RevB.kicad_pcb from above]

Board: 2 copper layers, 49.6 x 70.2 mm, 53 parts (1 on the bottom side), 100 nets.

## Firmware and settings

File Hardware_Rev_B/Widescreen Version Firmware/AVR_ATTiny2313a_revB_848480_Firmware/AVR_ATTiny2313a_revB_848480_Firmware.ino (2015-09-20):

// ONLY USE THIS WITH THE WIDESCREEN CPLD FIRMWARE!!!!!!!!!!!!

/* Firmware for the ATTiny 2313a on the VGAtonic board. */
//#define EEPROM_UPDATE 1 // Uncomment when you want to write EEPROM, otherwise leave this alone.
#include <avr/pgmspace.h>
#include <avr/eeprom.h>
#include "tinydefs.h"
#include "font.h"


/******************************************************************
 * 
 * VGATonic Control Signals
 * 
 *  VGATONIC_MODE             - Current State of VGATonic:
 *    0: Terminal Emulator Mode
 *    1: Terminal Emulator Mode Escape Character Interpreter
 *    2: Background Color Change Mode
 *    3: Foreground Color Change Mode
 *    4: Framebuffer Passthrough Mode (See Manual for Protocol)
 *    5: Control Character Passthrough Mode (See Manual for Details)
 *    6: Goto Line Number (ASCII Code minus 32)
 *    7: Goto Cursor Position (ASCII Code minus 32)
 *  CURRENT_LINE              - Current Line number.  Divide by 8 to find text line.
 *  CURRENT CURSOR            - Cursor position - 40 MAX Per Row.
 *  CURRENT_BACKGROUND_COLOR  - Active background color for terminal
 *  CURRENT_FOREGROUND_COLOR  - Active foreground color for terminal
 *  CURRENT_BUFFER            - Current characters in the active line
 *  SHOW_CURSOR               - Boolean; True if we are rendering the cursor
 *  RX_BUFF                   - Ring buffer of received characters over serial
 *    rxn:      pointer to active buffer element
 *    rx_flag:  raised when we receive a new byte.
 *  LTCCAL                    - Calibration byte for the LTC6903
 *  
 */
uint8_t VGATONIC_MODE = 0;
uint8_t CURRENT_LINE = 0;
uint8_t CURRENT_CURSOR = 0;
uint8_t CURRENT_BACKGROUND_COLOR = 0B00001100;
uint8_t CURRENT_FOREGROUND_COLOR = 0B00000000;
char    CURRENT_BUFFER[TERMINAL_LINE_MAX + 1] = "";
boolean SHOW_CURSOR = false;

// Volatile - Interrupts will edit these!
volatile char RX_BUFF[BUFFER_SIZE] = "";
volatile uint8_t rxn = 0; // buffer 'element' counter.
volatile uint8_t rx_flag = 0;

/*
 * These belong to the framebuffer
 */
uint8_t current_pixel_count = 0;
uint8_t LTCCAL; 


void setup() 
{
#ifdef EEPROM_UPDATE

  /* 
   *  Function should only run once, control it with the #define of EEPROM_UPDATE.
   *  It is defined in the utilities.ino file.
   * 
   */
  updateEEPROM();
  
#endif EEPROM_UPDATE

  //OSCCAL = eeprom_read_byte ((uint8_t*)OSCALSPEED);
  LTCCAL = eeprom_read_byte ((uint8_t*)LTCSPEED);
  
  
  // Set up LEDs
  DDRD  |= _BV(PD4);   // as output (LED 1)
  LED1_OFF;
  DDRD  |= _BV(PD5);   // as output (LED 2)
  LED2_OFF;
  

  bitbang_bytes_out();
  // Welcome message stored in EEPROM
  CPLD_TAKE;
  sendControlSignalToVGATonic(0B00000010); // 160x120, 256 colors
  CPLD_LOW;
  printLinesToScreen(0,120);
  uint8_t myCounter = 0;

  // Give control to external SPI (to write from computers, microcontrollers, etc.
  CPLD_HIGH;
  CPLD_GIVE;
  
  // Almost ready, turn on UART
  setup_uart();
}

/*
 * 
 * The microcontroller is a large state machine.  It starts in mode 0, but depending on key choices, here are all the modes:
 * 
 *  0   - vt52 Terminal Mode
 *  1   - vt52 Escape Character Interpretation (see terminal.ino file)
 *  2   - vt52 Change Background Color (Use the whole bit - the original only allowed 16 colors, we allow 256)
 *  3   - vt52 Change Foreground Color (Ditto)
 *  4   - VGATonic Framebuffer mode - allows passthrough UART -> SPI for VGATonic.
 *  5   - VGATonic control character - allow changing cursor position or resolution or color depth (all hardware functions)
 *  6&7 - vt52 'Y' Escape code - (6) allows us to set a y location, line 0 - 14.  (7) is for x location, 0 - 39.
 */
void loop()
{
#ifndef EEPROM_UPDATE

  if (rx_flag == 1) { // New UART Data
    rx_flag = 0;
    for (int i = 0; i < rxn; i++) { // For each new character received
      char currentChar = RX_BUFF[i];
      if        (VGATONIC_MODE == 7) { // 'Y' Set Position Cursor
        currentChar-= 32;
        if ( currentChar < 39) {
          CURRENT_CURSOR = currentChar;
          insCharRange(' ', 0, 38);
          uart_transmit(0x06);
        }
        VGATONIC_MODE = 0;
      } else if (VGATONIC_MODE == 6) { // 'Y' Set Position Line
        //CURRENT_LINE = (uint8_t)112;
        currentChar -= 32;
        if ( currentChar < 14) {
          CURRENT_LINE = (currentChar)*8;
          uart_transmit(0x06);
        }
        VGATONIC_MODE = 7;
      } else if (VGATONIC_MODE == 5) { // Send Control Character to VGATonic
        sendControlSignalToVGATonic(currentChar); VGATONIC_MODE = 0;
      } else if (VGATONIC_MODE == 4) { // UART Driven Framebuffer Mode
        handleFramebufferMode(currentChar);
      } else if (VGATONIC_MODE == 3) { // FG Color Change
        CURRENT_FOREGROUND_COLOR = currentChar; VGATONIC_MODE = 0;
      } else if (VGATONIC_MODE == 2) { // BG Color Change
        CURRENT_BACKGROUND_COLOR = currentChar; VGATONIC_MODE = 0;
      } else if (VGATONIC_MODE == 1 || VGATONIC_MODE == 8) { // Escape sequence
        interpretVT52EscapeSequence(currentChar);
      } else {
        handleTerminalMode(currentChar);
      }
      
      
      RX_BUFF[0] = 0x00;
      rxn = 0;
    }
  }

  
#endif EEPROM_UPDATE
}


/*
 * 'Framebuffer' mode - not fast over serial, but useful to show static images or slow animations on the lower resolutions.
 * 
 * 
 * All credit to Ward Christensen's 1977 XMODEM Protocol.  We send 150 bytes at a time though, not 128.
 * Also, we skip the CRC check since a bad pixel won't hurt us (or, at least, not much...)
 * 
 */
void handleFramebufferMode(const char currentChar) 
{
    spi_transfer(currentChar);
    ++current_pixel_count;
  // 150 is the highest number under 256 which divides evenly into all resolutions.
  if (150 == current_pixel_count) {
    VGATONIC_MODE = 0;
    uart_transmit(0x17);
  }
}


/*
 * Font retrieval function - 5 active lines plus a descender bit.
 * I wrote about the font here: https://hackaday.io/project/6309-vga-graphics-card-vgatonic/log/20759-a-tiny-4x6-pixel-font-that-will-fit-on-almost-any-microcontroller-license-mit
 */
unsigned char getFontLine(unsigned char data, int line_num) 
{
  //const uint8_t index = (data-32);
  data -= 33;
  if (data > 96) {
    return 0;
  }
  else {
    unsigned char pixel = 0;

    /*
     * The 'upper half' of characters is in the EEPROM, the 'lower half' in PROGMEM. 
     */
    uint8_t byte1 = eeprom_read_byte ( (uint8_t*)(FONTSTORAGE + data) );
    uint8_t byte2 = pgm_read_byte(&font4x6[data]);

    // Descender bit - if set, drop by one line
    if (byte2 & 1 == 1) line_num -= 1;

    // Font retrieval lines
    if (line_num == 0) {
      pixel = byte1 >> 4;
    } else if (line_num == 1) {
      pixel = byte1 >> 1;
    } else if (line_num == 2) {
      // This one is split over 2 bytes.  I put it at the 'end' of both.
      return ( (byte1 & 0x03) << 2) | (byte2 & 0x02) ;
    } else if (line_num == 3) {
      pixel = byte2 >> 4;
    } else if (line_num == 4) {
      pixel = byte2 >> 1;
    }
    return pixel & 0xE;
  }
}

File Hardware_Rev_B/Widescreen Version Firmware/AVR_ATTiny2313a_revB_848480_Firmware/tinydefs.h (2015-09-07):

/* Definitions File for Tiny 2313a Firmware on VGATonic Board */

#ifndef TINYDEFS_H
#define TINYDEFS_H

// EEPROM Locations - Don't change it unless you also update the EEPROM!  Beware: only 128 bytes available.
#define OSCALSPEED   0
#define LTCSPEED     1
#define HELLOMSG     2  // Welcome string
#define FONTSTORAGE  21 // Where the MSBs of our font reside.  We write 95 bytes from here.

// Serial Constants - Wishlist: change speed.
//#define USART_BAUDRATE 38400
#define F_CPU 7372800UL
#define BAUD_PRESCALE(baudrate)     (((F_CPU / (baudrate * 16UL))) - 1)
#define BAUD_PRESCALE_U2X(baudrate) (((F_CPU / (baudrate * 8UL))) - 1)

// Macros to flip IOs
#define CPLD_LOW     PORTB  &= ~(1 << PB0)
#define CPLD_HIGH    PORTB  |=  (1 << PB0)
#define CLK_LOW      PORTB  &= ~(1 << PB4)
#define CLK_HIGH     PORTB  |=  (1 << PB4)

#define CPLD_GIVE    PORTB  &= ~(1 << PB1)
#define CPLD_TAKE    PORTB  |=  (1 << PB1)

#define SCK_LOW      PORTB  &= ~(1 << PB7)
#define SCK_HIGH     PORTB  |=  (1 << PB7)
#define DI_LOW       PORTB  &= ~(1 << PB5)
#define DI_HIGH      PORTB  |=  (1 << PB5)

// SPI Definitions
#define SCK_LOW      PORTB  &= ~(1 << PB7)
#define SCK_HIGH     PORTB  |= (1 << PB7)
#define DI_LOW       PORTB  &= ~(1 << PB5)
#define DI_HIGH      PORTB  |= (1 << PB5)

//UART Definitions
#define BUFFER_SIZE  128
#define TERMINAL_LINE_MAX 40
#define NO_DATA      0x0100
#define OFF_U2X      UCSRA &= ~(1 << U2X);
#define USE_U2X      UCSRA |= (1 << U2X);

// LED Definitions

#define LED1_ON      PORTD  &= ~(1 << PD4);
#define LED1_OFF     PORTD  |=  (1 << PD4)
#define LED2_ON      PORTD  &= ~(1 << PD5);
#define LED2_OFF     PORTD  |=  (1 << PD5)

#endif

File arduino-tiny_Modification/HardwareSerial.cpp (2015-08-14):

/*
  HardwareSerial.cpp - Hardware serial library for Wiring
  Copyright (c) 2006 Nicholas Zambetti.  All right reserved.

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
  Modified 23 November 2006 by David A. Mellis
  Modified 28 September 2010 by Mark Sproul
*/

#include <stdlib.h>
#include <stdio.h>
#include <string.h>
#include <inttypes.h>


#if 0
#include "core_build_options.h"
#include "wiring.h"
#include "wiring_private.h"

// this next line disables the entire HardwareSerial.cpp,
// this is so I can support Attiny series and any other chip without a uart
#if defined(UBRRH) || defined(UBRR0H) || defined(UBRR1H) || defined(UBRR2H) || defined(UBRR3H)

#include "HardwareSerial.h"

// Define constants and variables for buffering incoming serial data.  We're
// using a ring buffer (I think), in which rx_buffer_head is the index of the
// location to which to write the next incoming character and rx_buffer_tail
// is the index of the location from which to read.
#if (RAMEND < 1000)
  #define RX_BUFFER_SIZE 32
#else
  #define RX_BUFFER_SIZE 128
#endif

struct ring_buffer
{
  unsigned char buffer[RX_BUFFER_SIZE];
  int head;
  int tail;
};

#if defined(UBRRH) || defined(UBRR0H)
  ring_buffer rx_buffer  =  { { 0 }, 0, 0 };
#endif
#if defined(UBRR1H)
  ring_buffer rx_buffer1  =  { { 0 }, 0, 0 };
#endif
#if defined(UBRR2H)
  ring_buffer rx_buffer2  =  { { 0 }, 0, 0 };
#endif
#if defined(UBRR3H)
  ring_buffer rx_buffer3  =  { { 0 }, 0, 0 };
#endif

inline void store_char(unsigned char c, ring_buffer *rx_buffer)
{
  int i = (unsigned int)(rx_buffer->head + 1) % RX_BUFFER_SIZE;

  // if we should be storing the received character into the location
  // just before the tail (meaning that the head would advance to the
  // current location of the tail), we're about to overflow the buffer
  // and so we don't write the character or advance the head.
  if (i != rx_buffer->tail) {
    rx_buffer->buffer[rx_buffer->head] = c;
    rx_buffer->head = i;
  }
}

#if defined(USART_RX_vect)
  ISR(USART_RX_vect)
  {
  #if defined(UDR0)
    unsigned char c  =  UDR0;
  #elif defined(UDR)
    unsigned char c  =  UDR;  //  atmega8535
  #else
    #error UDR not defined
  #endif
    store_char(c, &rx_buffer);
  }
#elif defined(USART0_RECV_vect) && defined(UDR0)
  ISR(USART0_RECV_vect)
  {
    unsigned char c  =  UDR0;
    store_char(c, &rx_buffer);
  }
#elif defined(UART0_RECV_vect) && defined(UDR0)
  ISR(UART0_RECV_vect)
  {
    unsigned char c  =  UDR0;
    store_char(c, &rx_buffer);
  }
//#elif defined(SIG_USART_RECV)
#elif defined(USART0_RX_vect)
  // fixed by Mark Sproul this is on the 644/644p
  //ISR(SIG_USART_RECV)
  ISR(USART0_RX_vect)
  {
  #if defined(UDR0)
    unsigned char c  =  UDR0;
  #elif defined(UDR)
    unsigned char c  =  UDR;  //  atmega8, atmega32
  #else
    #error UDR not defined
  #endif
    store_char(c, &rx_buffer);
  }
#elif defined(UART_RECV_vect)
  // this is for atmega8
  ISR(UART_RECV_vect)
  {
  #if defined(UDR0)
    unsigned char c  =  UDR0;  //  atmega645
  #elif defined(UDR)
    unsigned char c  =  UDR;  //  atmega8
  #endif
    store_char(c, &rx_buffer);
  }
#elif defined(USBCON)
  #warning No interrupt handler for usart 0
  #warning Serial(0) is on USB interface
#else
  #error No interrupt handler for usart 0
#endif

//#if defined(SIG_USART1_RECV)
#if defined(USART1_RX_vect)
  //ISR(SIG_USART1_RECV)
  ISR(USART1_RX_vect)
  {
    unsigned char c = UDR1;
    store_char(c, &rx_buffer1);
  }
#endif

#if defined(USART2_RX_vect) && defined(UDR2)
  ISR(USART2_RX_vect)
  {
    unsigned char c = UDR2;
    store_char(c, &rx_buffer2);
  }
#endif

#if defined(USART3_RX_vect) && defined(UDR3)
  ISR(USART3_RX_vect)
  {
    unsigned char c = UDR3;
    store_char(c, &rx_buffer3);
  }
#endif



// Constructors ////////////////////////////////////////////////////////////////

HardwareSerial::HardwareSerial(ring_buffer *rx_buffer,
  volatile uint8_t *ubrrh, volatile uint8_t *ubrrl,
  volatile uint8_t *ucsra, volatile uint8_t *ucsrb,
  volatile uint8_t *udr,
  uint8_t rxen, uint8_t txen, uint8_t rxcie, uint8_t udre, uint8_t u2x)
{
  _rx_buffer = rx_buffer;
  _ubrrh = ubrrh;
  _ubrrl = ubrrl;
  _ucsra = ucsra;
  _ucsrb = ucsrb;
  _udr = udr;
  _rxen = rxen;
  _txen = txen;
  _rxcie = rxcie;
  _udre = udre;
  _u2x = u2x;
}

// Public Methods //////////////////////////////////////////////////////////////

void HardwareSerial::begin(long baud)
{
  uint16_t baud_setting;
  bool use_u2x = true;

#if F_CPU == 16000000UL
  // hardcoded exception for compatibility with the bootloader shipped
  // with the Duemilanove and previous boards and the firmware on the 8U2
  // on the Uno and Mega 2560.
  if (baud == 57600) {
    use_u2x = false;
  }
#endif
  
  if (use_u2x) {
    *_ucsra = 1 << _u2x;
    baud_setting = (F_CPU / 4 / baud - 1) / 2;
  } else {
    *_ucsra = 0;
    baud_setting = (F_CPU / 8 / baud - 1) / 2;
  }

  // assign the baud_setting, a.k.a. ubbr (USART Baud Rate Register)
  *_ubrrh = baud_setting >> 8;
  *_ubrrl = baud_setting;

  sbi(*_ucsrb, _rxen);
  sbi(*_ucsrb, _txen);
  sbi(*_ucsrb, _rxcie);
}

void HardwareSerial::end()
{
  cbi(*_ucsrb, _rxen);
  cbi(*_ucsrb, _txen);
  cbi(*_ucsrb, _rxcie);  
}

int HardwareSerial::available(void)
{
  return (unsigned int)(RX_BUFFER_SIZE + _rx_buffer->head - _rx_buffer->tail) % RX_BUFFER_SIZE;
}

int HardwareSerial::peek(void)
{
  if (_rx_buffer->head == _rx_buffer->tail) {
    return -1;
  } else {
    return _rx_buffer->buffer[_rx_buffer->tail];
  }
}

int HardwareSerial::read(void)
{
  // if the head isn't ahead of the tail, we don't have any characters
  if (_rx_buffer->head == _rx_buffer->tail) {
    return -1;
  } else {
    unsigned char c = _rx_buffer->buffer[_rx_buffer->tail];
    _rx_buffer->tail = (unsigned int)(_rx_buffer->tail + 1) % RX_BUFFER_SIZE;
    return c;
  }
}

void HardwareSerial::flush()
{
  // don't reverse this or there may be problems if the RX interrupt
  // occurs after reading the value of rx_buffer_head but before writing
  // the value to rx_buffer_tail; the previous value of rx_buffer_head
  // may be written to rx_buffer_tail, making it appear as if the buffer
  // don't reverse this or there may be problems if the RX interrupt
  // occurs after reading the value of rx_buffer_head but before writing
  // the value to rx_buffer_tail; the previous value of rx_buffer_head
  // may be written to rx_buffer_tail, making it appear as if the buffer
  // were full, not empty.
  _rx_buffer->head = _rx_buffer->tail;
}

size_t HardwareSerial::write(uint8_t c)
{
  while (!((*_ucsra) & (1 << _udre)))
    ;

  *_udr = c;

  return( 1 );
}

// Preinstantiate Objects //////////////////////////////////////////////////////
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

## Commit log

2014-07-27 Create SPISlave.vhd
    SPI Slave exaple, with clock domain crossing to user logic.
2014-07-27 Create README.md
    Readme for the SPI Slave example.
2014-08-10 Adding reference and build documentation
    [VGAtonic.kicad_pcb, VGAtonic_BOM.csv, VGAtonic_pg_1.sch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]
2014-09-03 Adding userland code from Arduino
2015-06-01 Userland driver for VGAtonic (based on RPi 2 B, but easily adaptable\!)
2015-06-01 Adding Framebuffer driver for Raspberry Pi 2 B
2015-06-08 Raspberry Pi 62.5 MHz SPI because 58 MHz is nonsense (rounds to 31.25 MHz)
2015-06-15 Didn't see that Page 1 of the Schematic was impossible to see. So, making it easier to see with a new PDF of page 1.
2015-07-07 SPI Slave code with support for AVR writing SPI to VGATonic
2015-07-29 Fixed DMA, Added Pseudo Color Bit (Always 16), Changed SPI Write Buffer to kmalloc from vzalloc, BBB working properly, Intel Edison Added.
    [edison_vgatonic_spi.c, vgatonic.c]
2015-08-09 Build details
    [VGAtonic.kicad_pcb, VGAtonic_BOM.csv, VGAtonic_pg_1.sch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]
2015-08-12 Licenses more explicit, updating BBB frames per second to 19.25
2015-08-14 Modification to LGPL arduino-tiny code
2015-08-16 Arduino driver, hardware acceleration
2015-08-17 Update README.md
    License change, BOM.
2015-09-07 Rev B - smaller, faster, stronger, better looking
    [OutputsAndInputs.sch, OutputsAndInputsold.sch, VGATonic RevB BOM.csv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]
2015-09-20 Widescreen drivers are now in there
2015-09-20 Firmware for widescreen rev B board both Microcontroller and CPLD
